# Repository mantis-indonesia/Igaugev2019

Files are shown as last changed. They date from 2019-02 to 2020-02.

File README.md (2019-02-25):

# Igaugev2019
Open source hardware water pressure sensor measurement system using Arduino Mega 2560

# Development
This system develop by Team MANTIS ID collaborate with USAID - IUWASH PLUS, PDAM Tirta Pakuan Kota Bogor, PDAM Tirta Patriot Kota Bekasi, and PDAM Tirta Asasta Kota Depok

# Folder
1. **Arduino Library** : All arduino external library used in this development
2. **Igauge_V2019** : Arduino Sketch used in this system
3. **Manual & Material** : All datasheet, and learning materials from components used in this system
4. **WEMOS_IGAUGE** : Arduino sketch for ESP Unit System
5. **nRFRangeTestRX** : Arduino sketch for NRF24L01 Experiment. This sketch used in server side
6. **nRFRangeTestTX** : Arduino sketch for NRF24L01 Experiment. This sketch used in transmitter side

# Developer
- Hollanda Arief Kusuma : github.com/hollandacocobear
- Rady P

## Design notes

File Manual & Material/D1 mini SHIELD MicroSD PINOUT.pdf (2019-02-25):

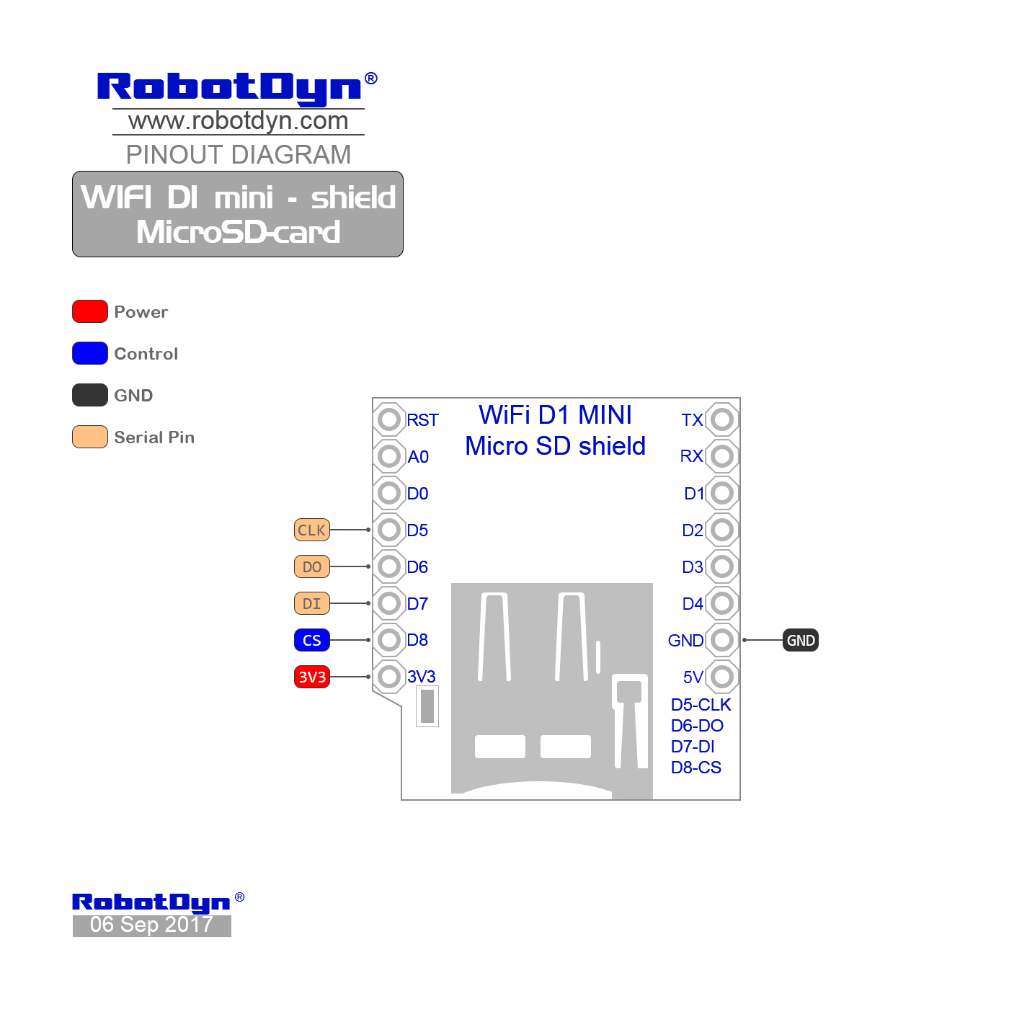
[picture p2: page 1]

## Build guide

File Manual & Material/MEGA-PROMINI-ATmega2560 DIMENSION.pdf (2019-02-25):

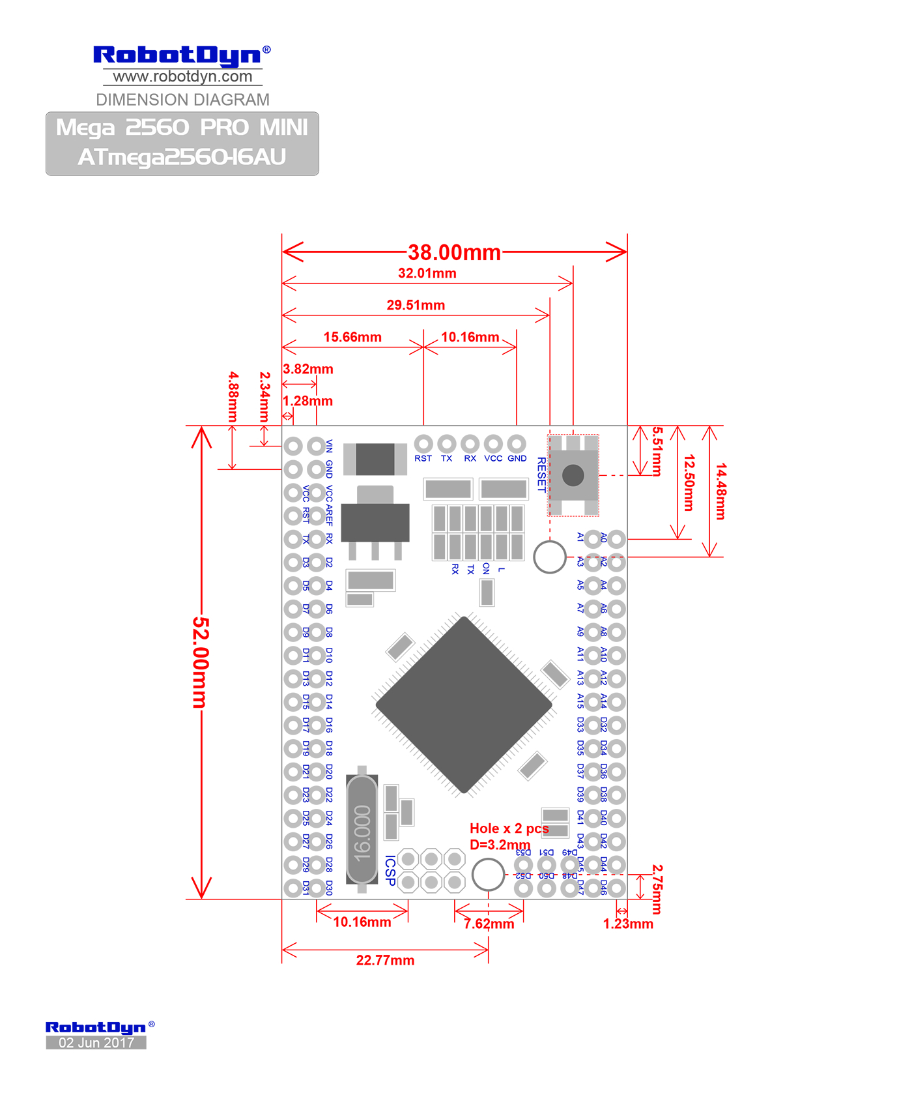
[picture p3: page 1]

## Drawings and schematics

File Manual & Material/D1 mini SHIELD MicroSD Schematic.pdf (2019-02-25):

11

22

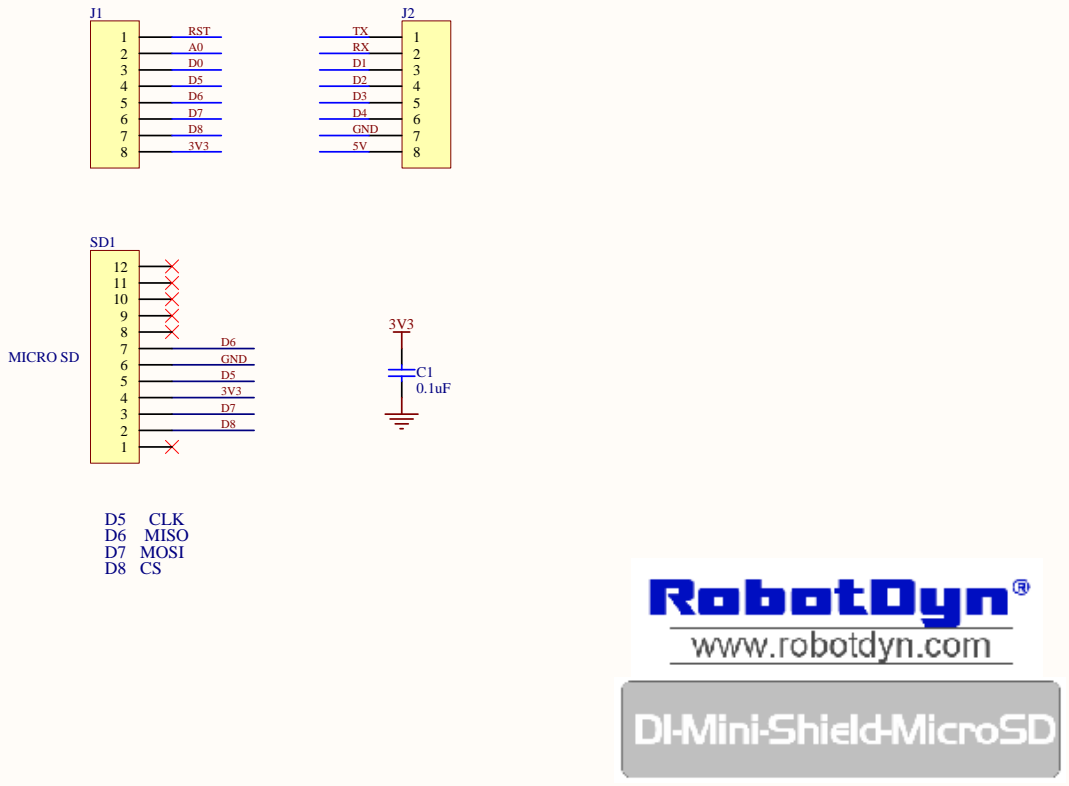
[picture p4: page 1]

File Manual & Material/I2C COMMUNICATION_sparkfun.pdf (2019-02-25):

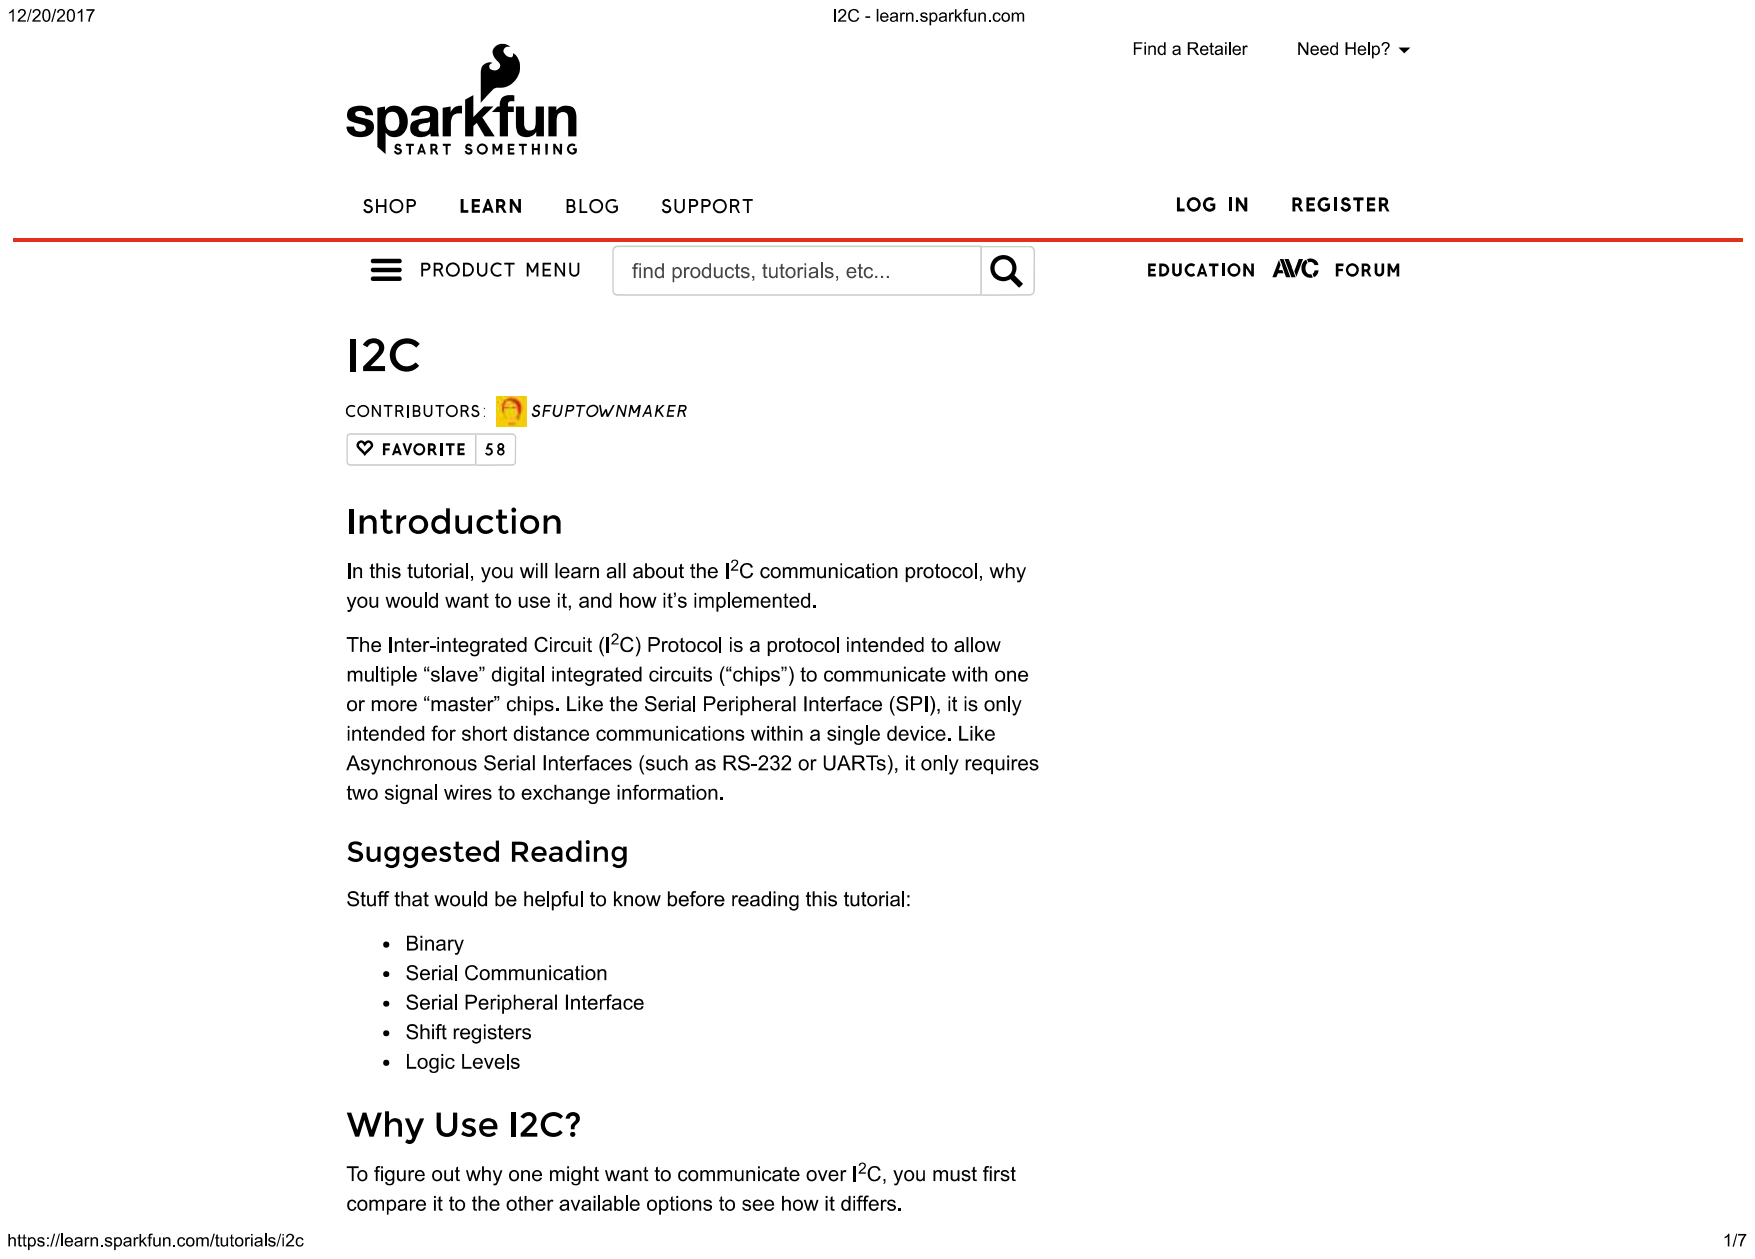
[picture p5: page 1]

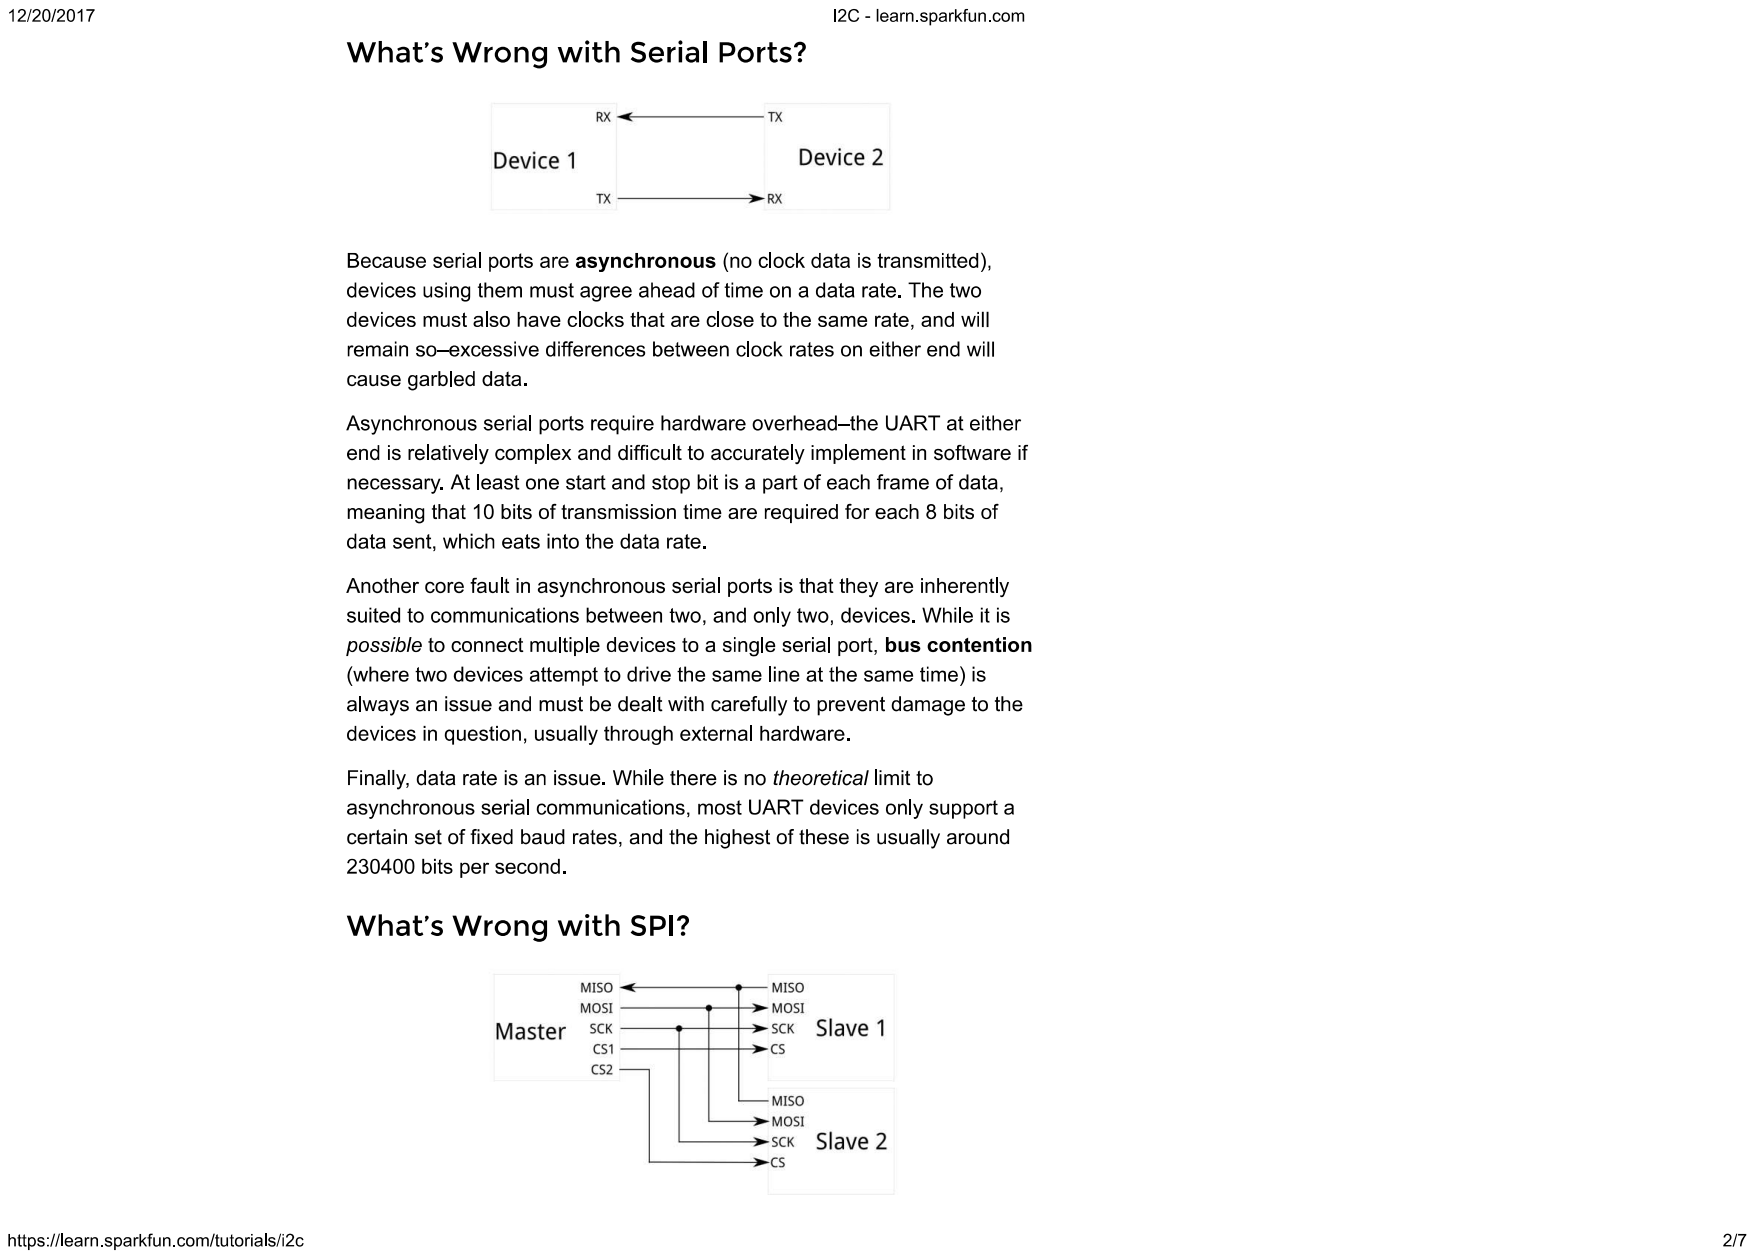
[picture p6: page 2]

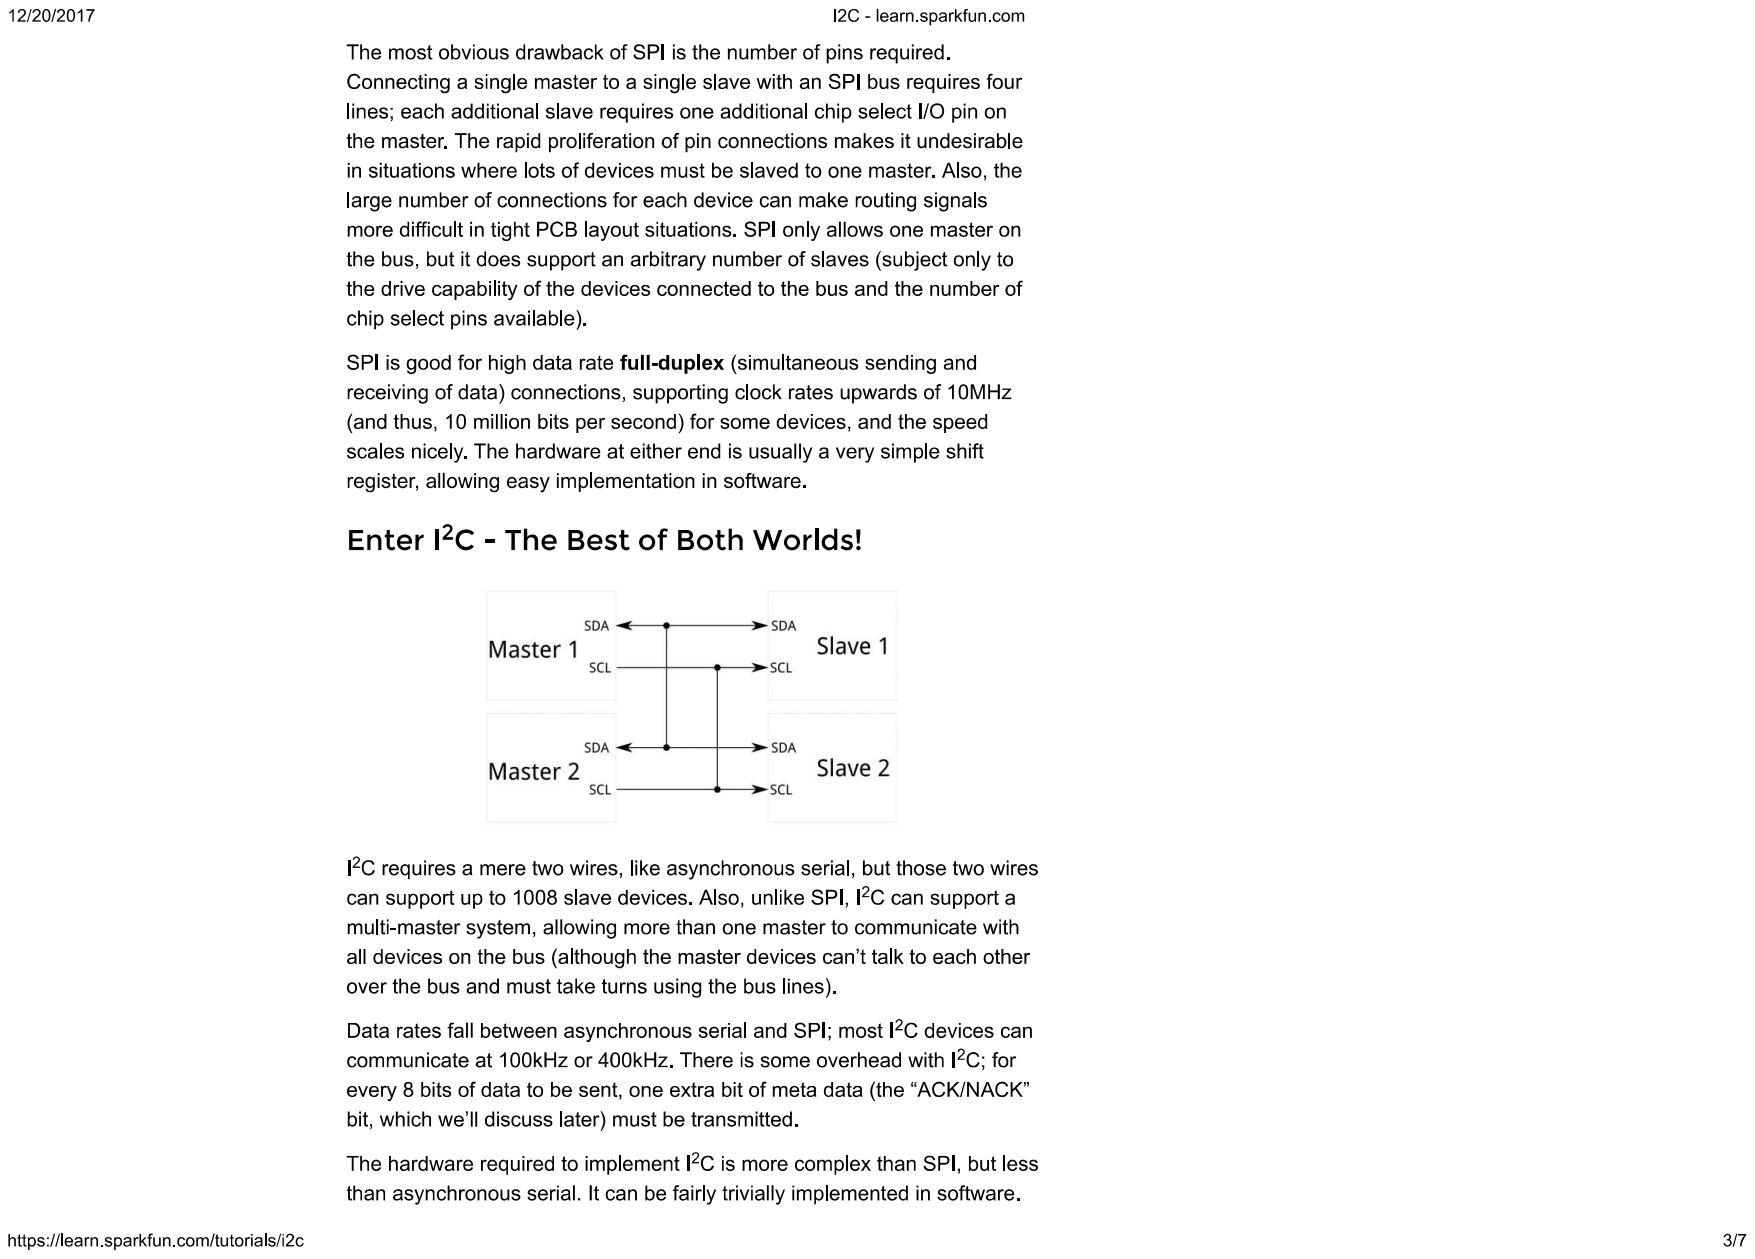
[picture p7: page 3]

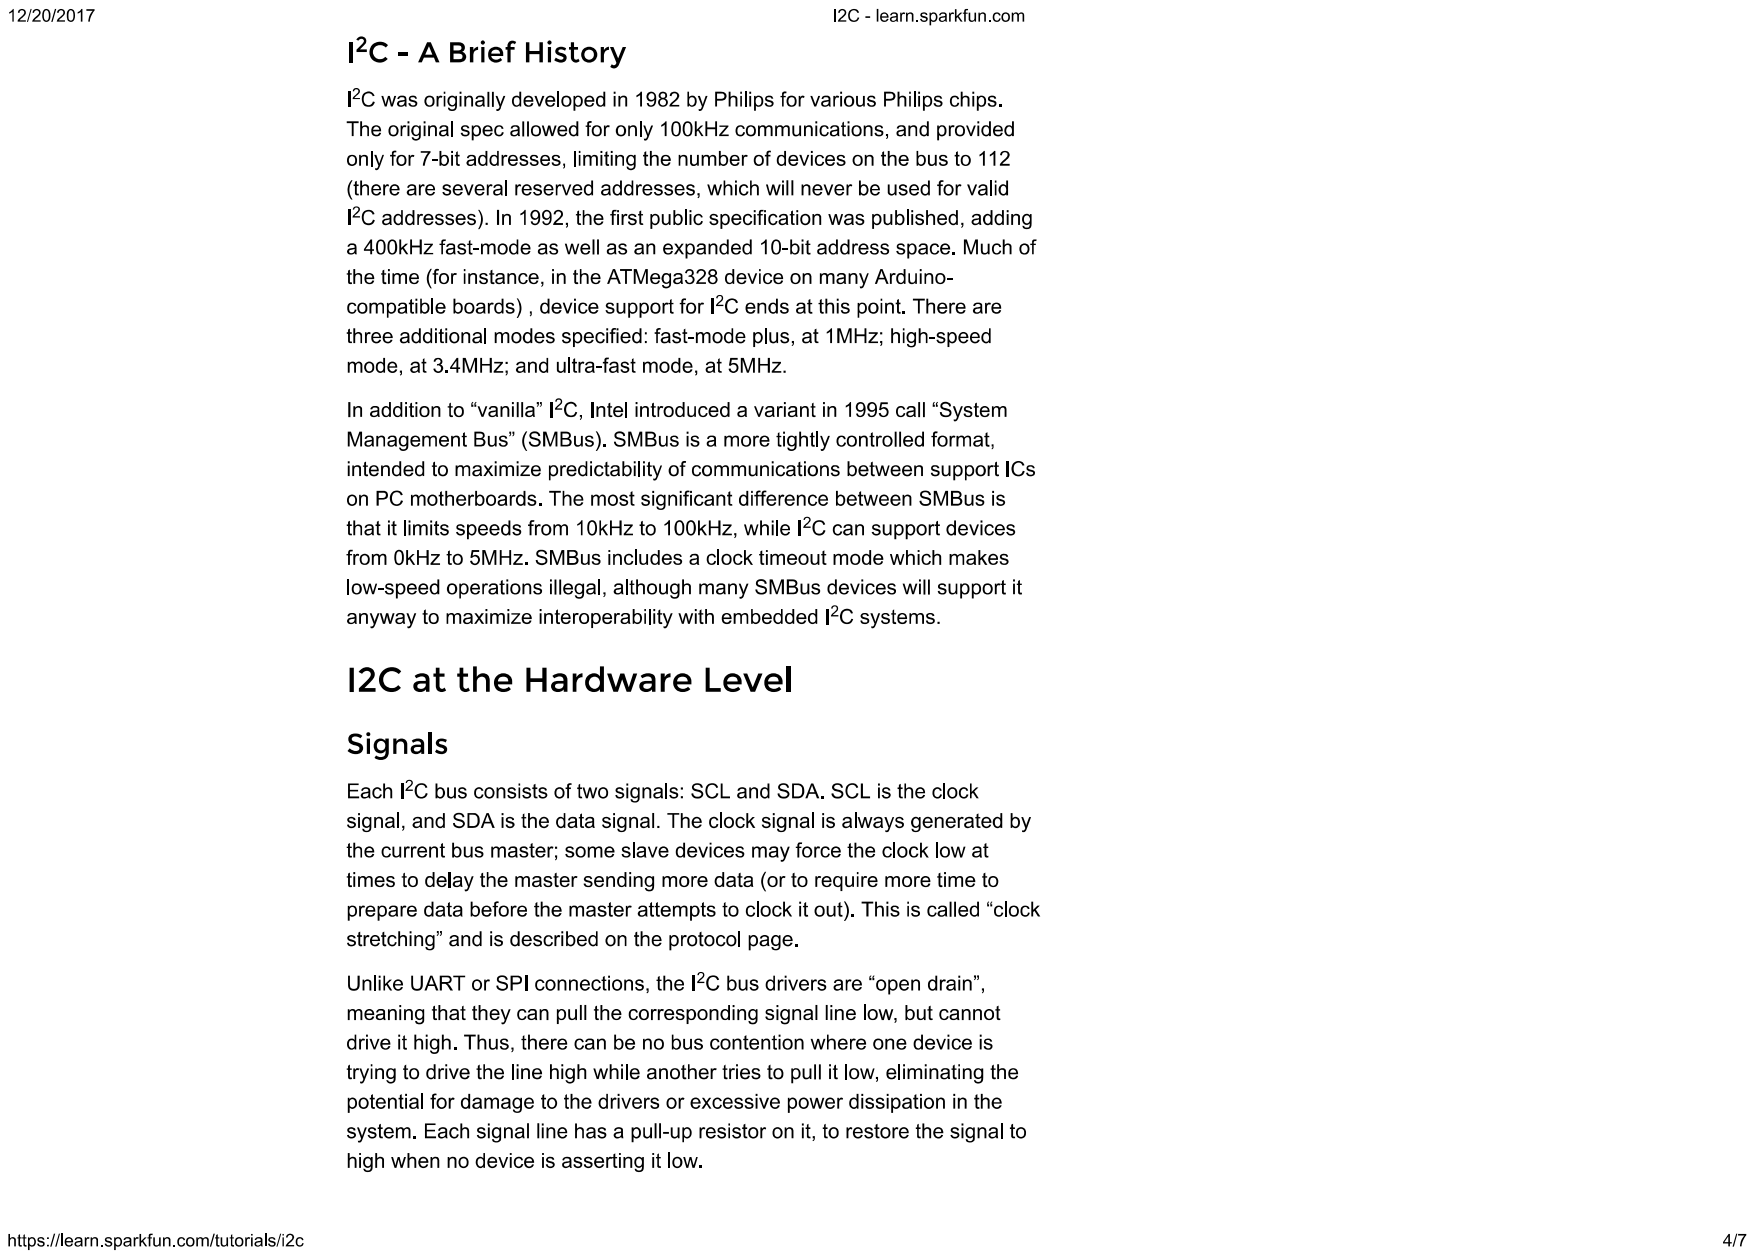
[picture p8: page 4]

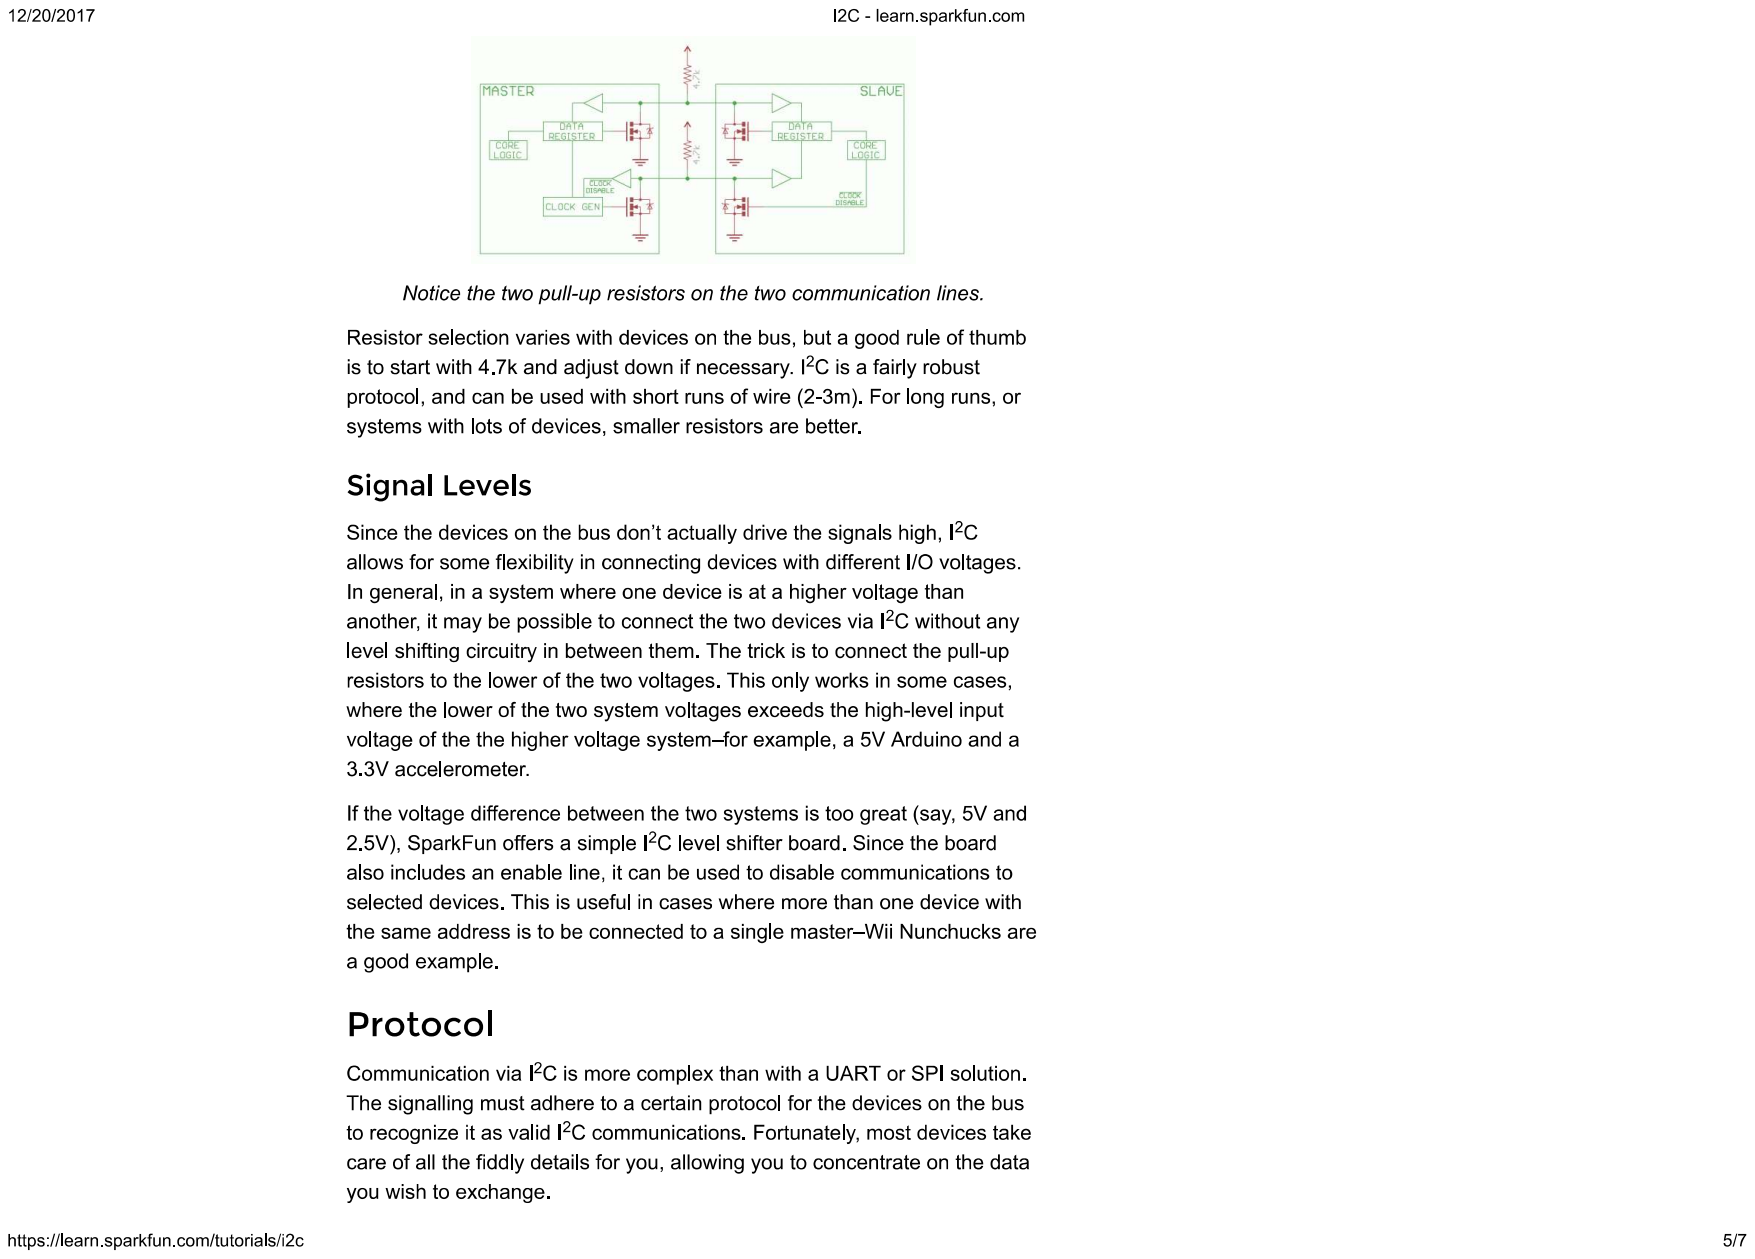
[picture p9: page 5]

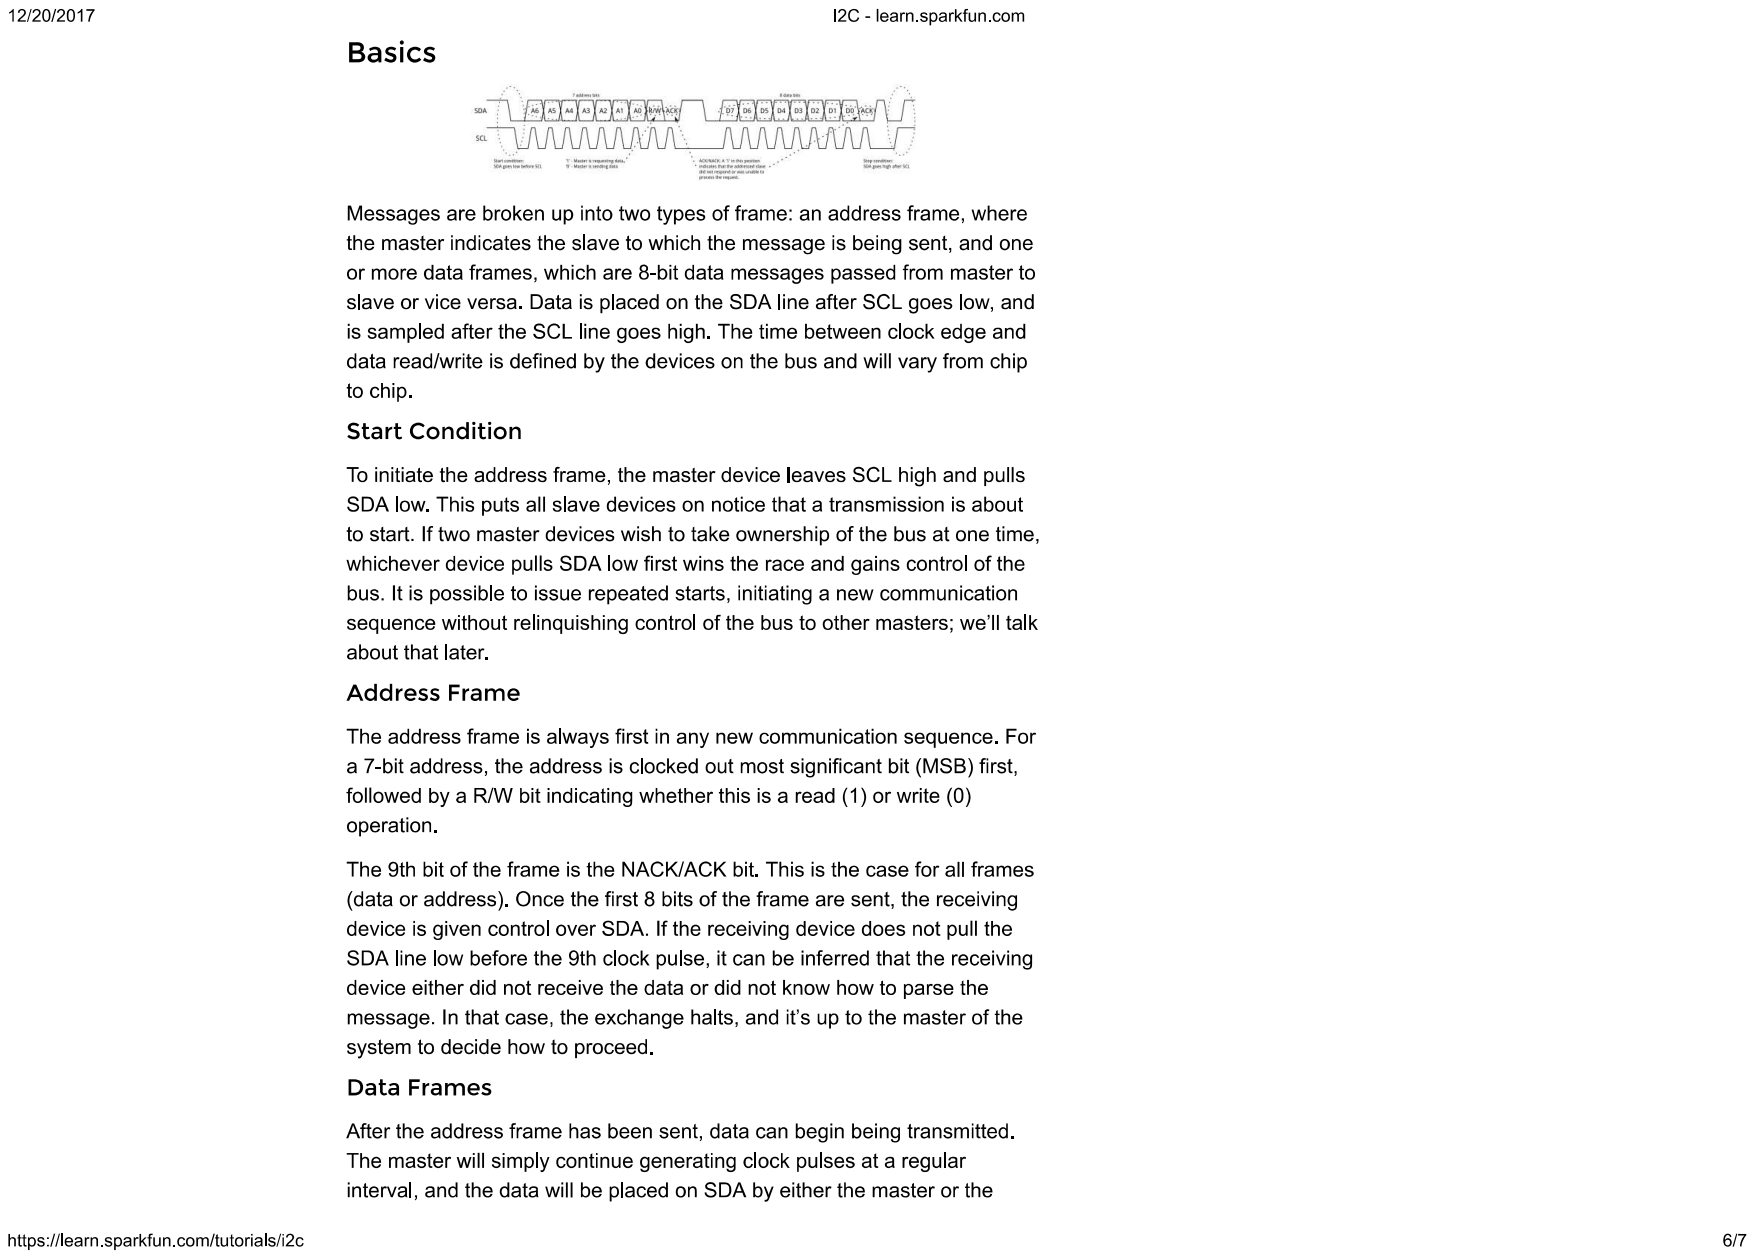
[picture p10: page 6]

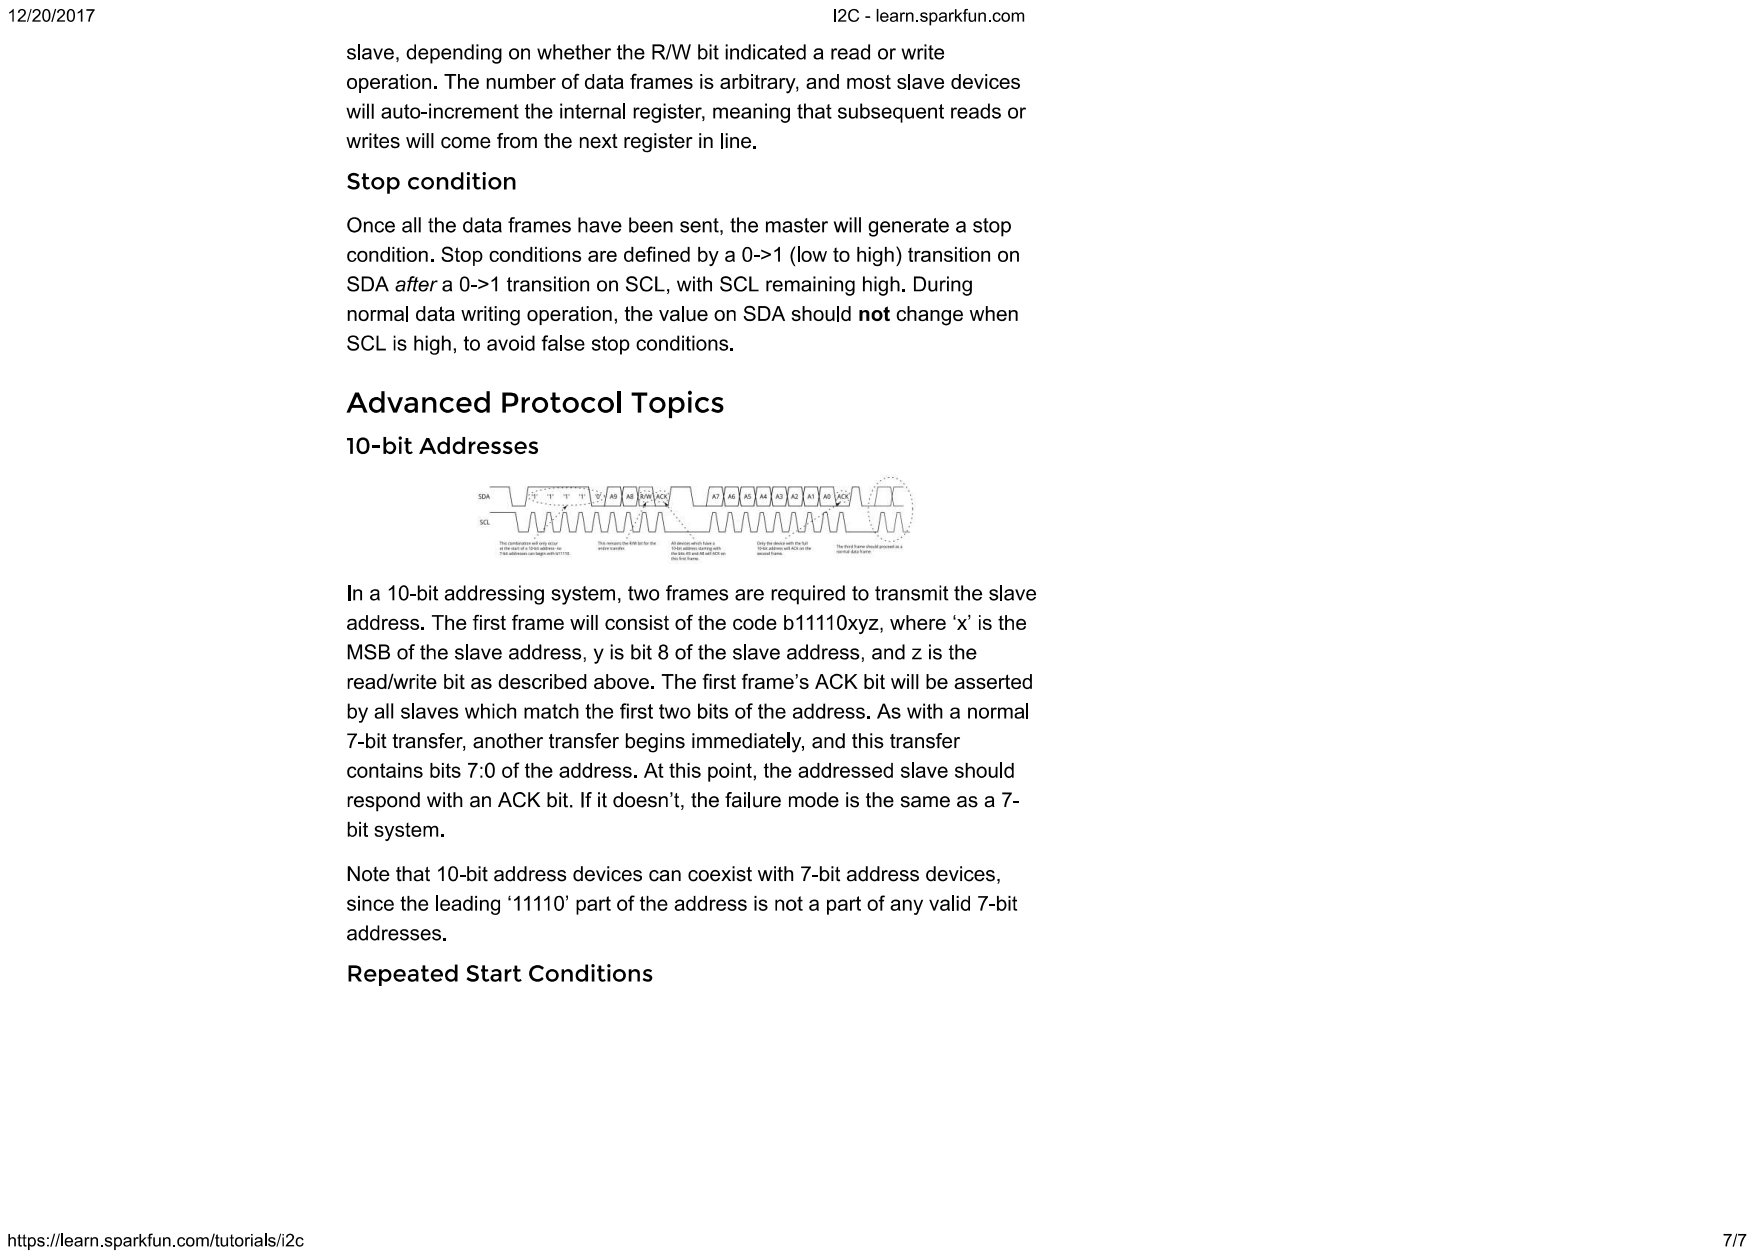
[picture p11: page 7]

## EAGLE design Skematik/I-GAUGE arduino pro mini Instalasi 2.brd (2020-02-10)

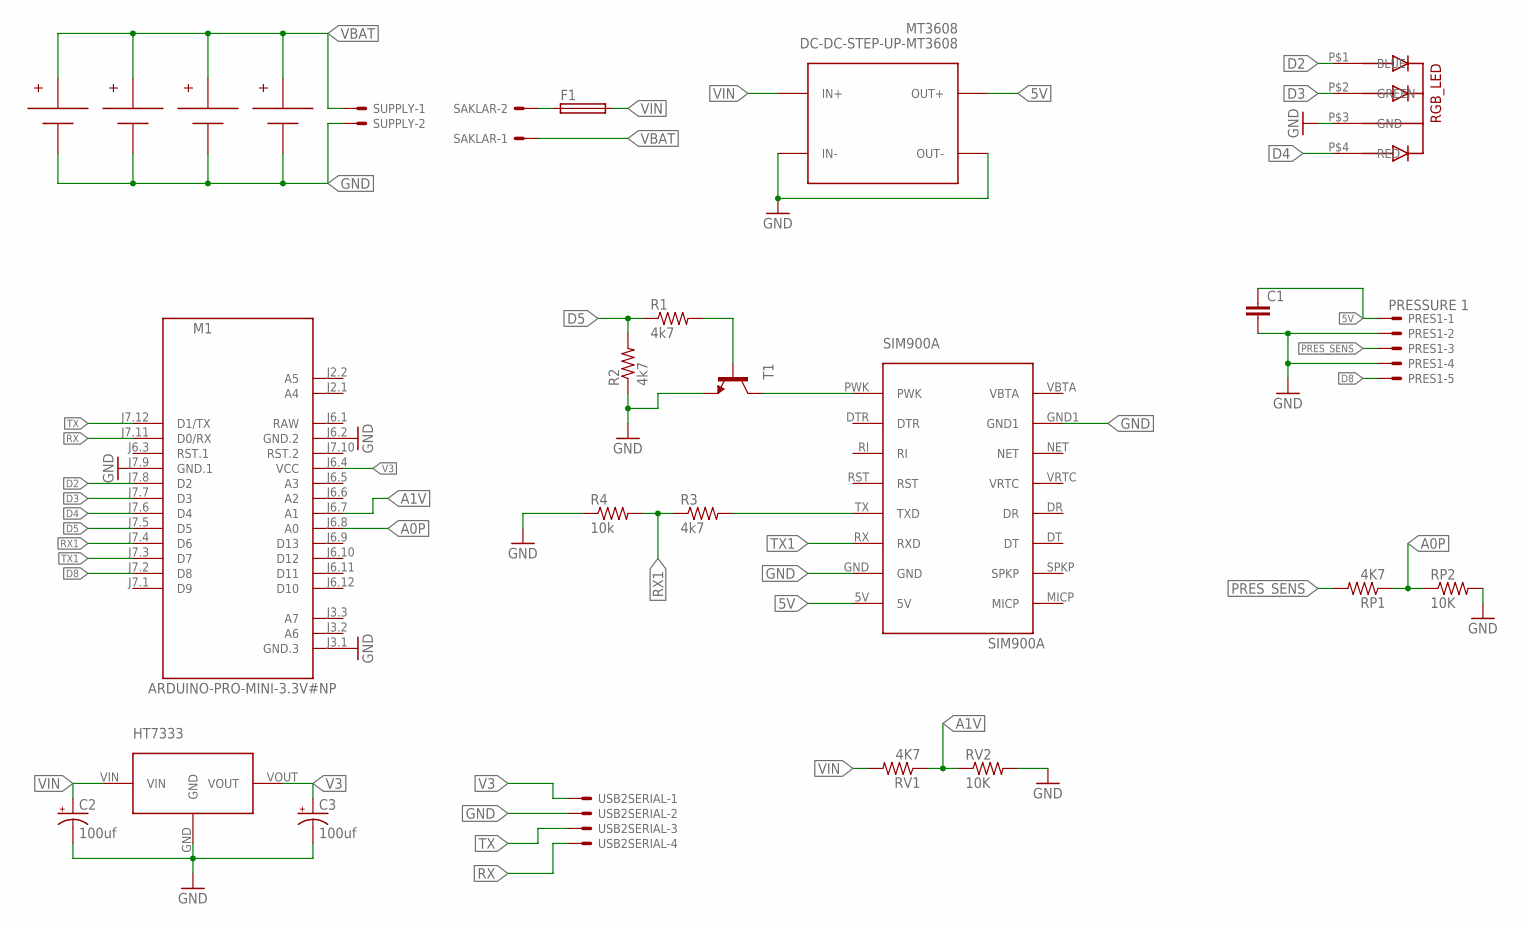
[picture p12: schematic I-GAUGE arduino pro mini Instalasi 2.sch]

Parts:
C1: C-EUC1206; C1206
C2, C3: 100uf; CT7343
F1: FUSESH22,5; SH22,5
HT7333: HT7333_SOT89; SOT89
M1: ARDUINO-PRO-MINI-3.3V#NP; ARDUINO-PRO-MINI#NP
MT3608: DC-DC-STEP-UP-MT3608
PRES1: PRESSURE 1; JST-XH-05-PACKAGE-ROUND-PAD
R1, R2: 4k7; R1206
R3: 4k7; 1206
R4: 10k; R1206
RGB_LED: 5MMRGBLED; LED5MMRGB
RP1: 4K7; M1206
RP2: 10K; M1206
RV1: 4K7; M1206
RV2: 10K; M1206
SAKLAR: JST-XH-02-PIN-ROUND-PAD; JST-XH-02-PACKAGE-ROUND-PAD
SUPPLY: JST-XH-02-PIN-ROUND-PAD; JST-XH-02-PACKAGE-ROUND-PAD
T1: -NPN-TO92; TO92
U$1, U$2, U$3, U$4: SMT18650; 18650SMT
U$6: SIM900A
USB2SERIAL: JST-XH-04-PIN-ROUND-PAD; JST-XH-04-PACKAGE-ROUND-PAD

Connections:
5V: C1.1, MT3608.OUT+, PRES1.1, U$6.5V
A0P: M1.J6.8 (A0), RP1.1, RP2.1
A1V: M1.J6.7 (A1), RV1.1, RV2.1
D2: M1.J7.8 (D2), RGB_LED.P$1 (BLUE)
D3: M1.J7.7 (D3), RGB_LED.P$2 (GREEN)
D4: M1.J7.6 (D4), RGB_LED.P$4 (RED)
D5: M1.J7.5 (D5), R1.1, R2.2
D8: M1.J7.2 (D8), PRES1.5
GND: C1.2, C2.-, C3.-, HT7333.GND, M1.J3.1 (GND.3), M1.J6.2 (GND.2), M1.J7.9 (GND.1), MT3608.IN-, MT3608.OUT-, PRES1.2, PRES1.4, R2.1, R4.1, RGB_LED.P$3 (GND), RP2.2, RV2.2, SUPPLY.2, T1.1 (E), U$1.BATTERY_NEGATIVE (-), U$2.BATTERY_NEGATIVE (-), U$3.BATTERY_NEGATIVE (-), U$4.BATTERY_NEGATIVE (-), U$6.GND, U$6.GND1, USB2SERIAL.2
unnamed: R1.2, T1.2 (B)
unnamed: R3.2, U$6.TX (TXD)
unnamed: T1.3 (C), U$6.PWK
PRES_SENS: PRES1.3, RP1.2
RAW: M1.J6.1 (RAW)
RX: M1.J7.11 (D0/RX), USB2SERIAL.4
RX1: M1.J7.4 (D6), R3.1, R4.2
TX: M1.J7.12 (D1/TX), USB2SERIAL.3
TX1: M1.J7.3 (D7), U$6.RX (RXD)
V3: C3.+, HT7333.VOUT, M1.J6.4 (VCC), USB2SERIAL.1
VBAT: SAKLAR.1, SUPPLY.1, U$1.BATTERY_POSITIVE (+), U$2.BATTERY_POSITIVE (+), U$3.BATTERY_POSITIVE (+), U$4.BATTERY_POSITIVE (+)
VCC: F1.1, SAKLAR.2
VIN: C2.+, F1.2, HT7333.VIN, MT3608.IN+, RV1.2

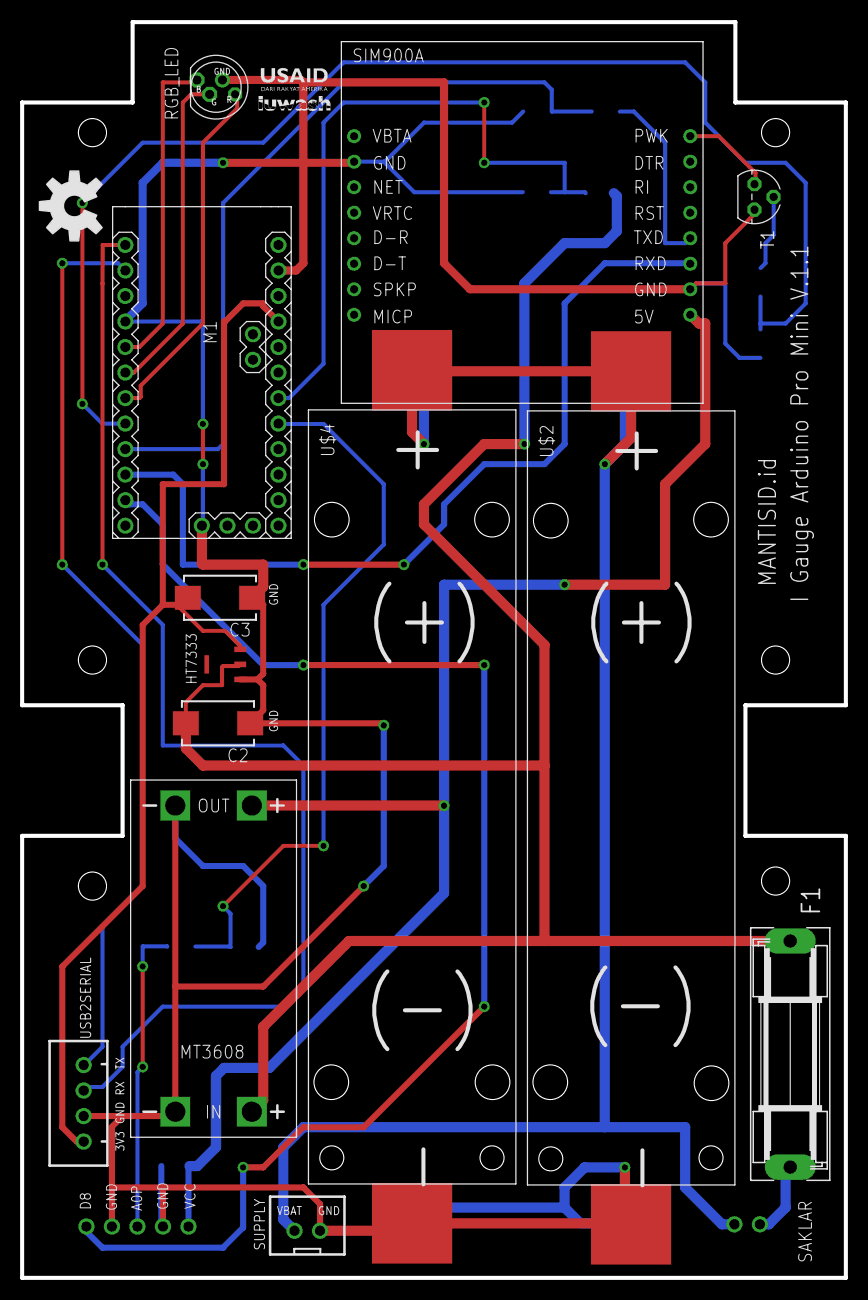
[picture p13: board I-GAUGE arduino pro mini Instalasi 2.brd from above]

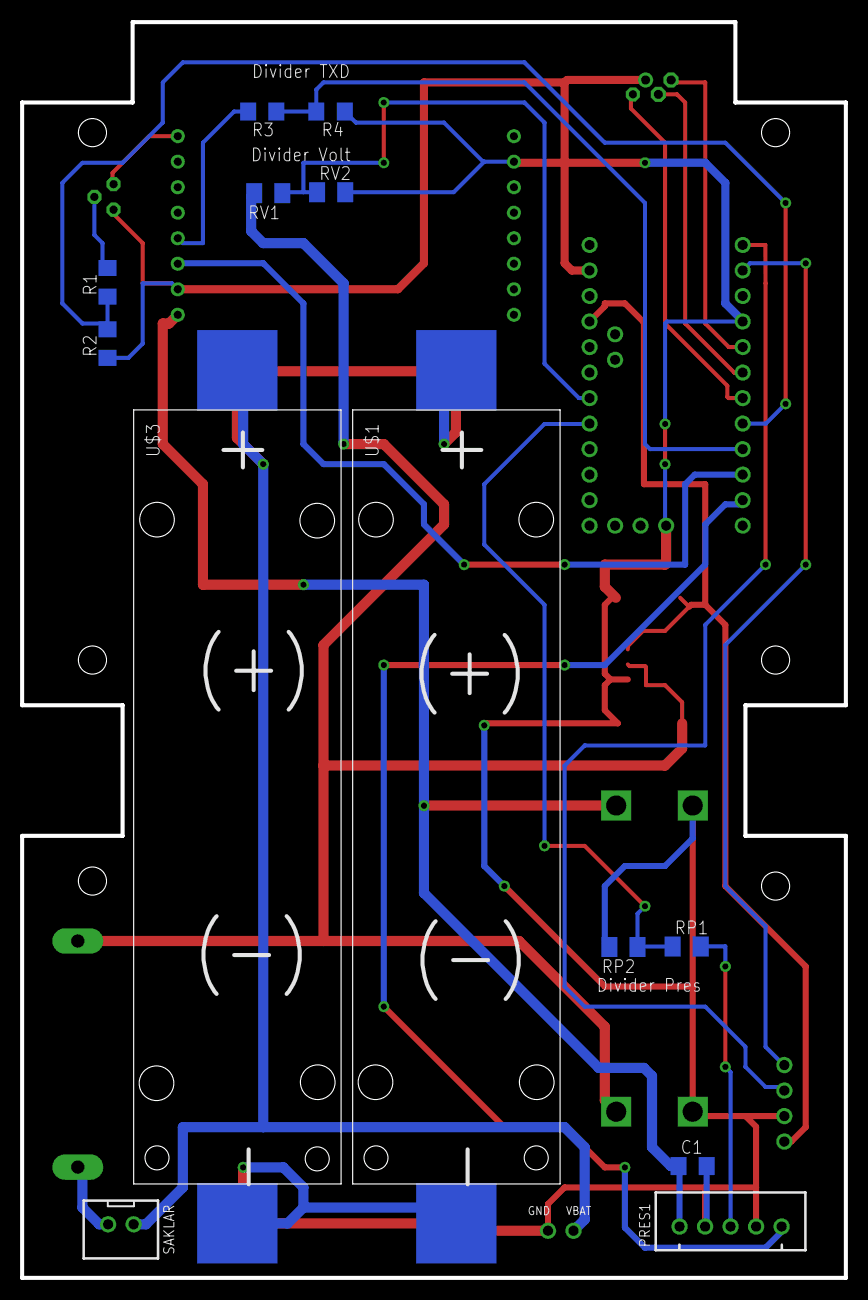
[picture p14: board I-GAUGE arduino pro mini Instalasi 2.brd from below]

Board: 2 copper layers, 82.0 x 125.0 mm, 27 parts (13 on the bottom side), 21 nets.

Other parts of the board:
U$7: OSHW-LOGO-L

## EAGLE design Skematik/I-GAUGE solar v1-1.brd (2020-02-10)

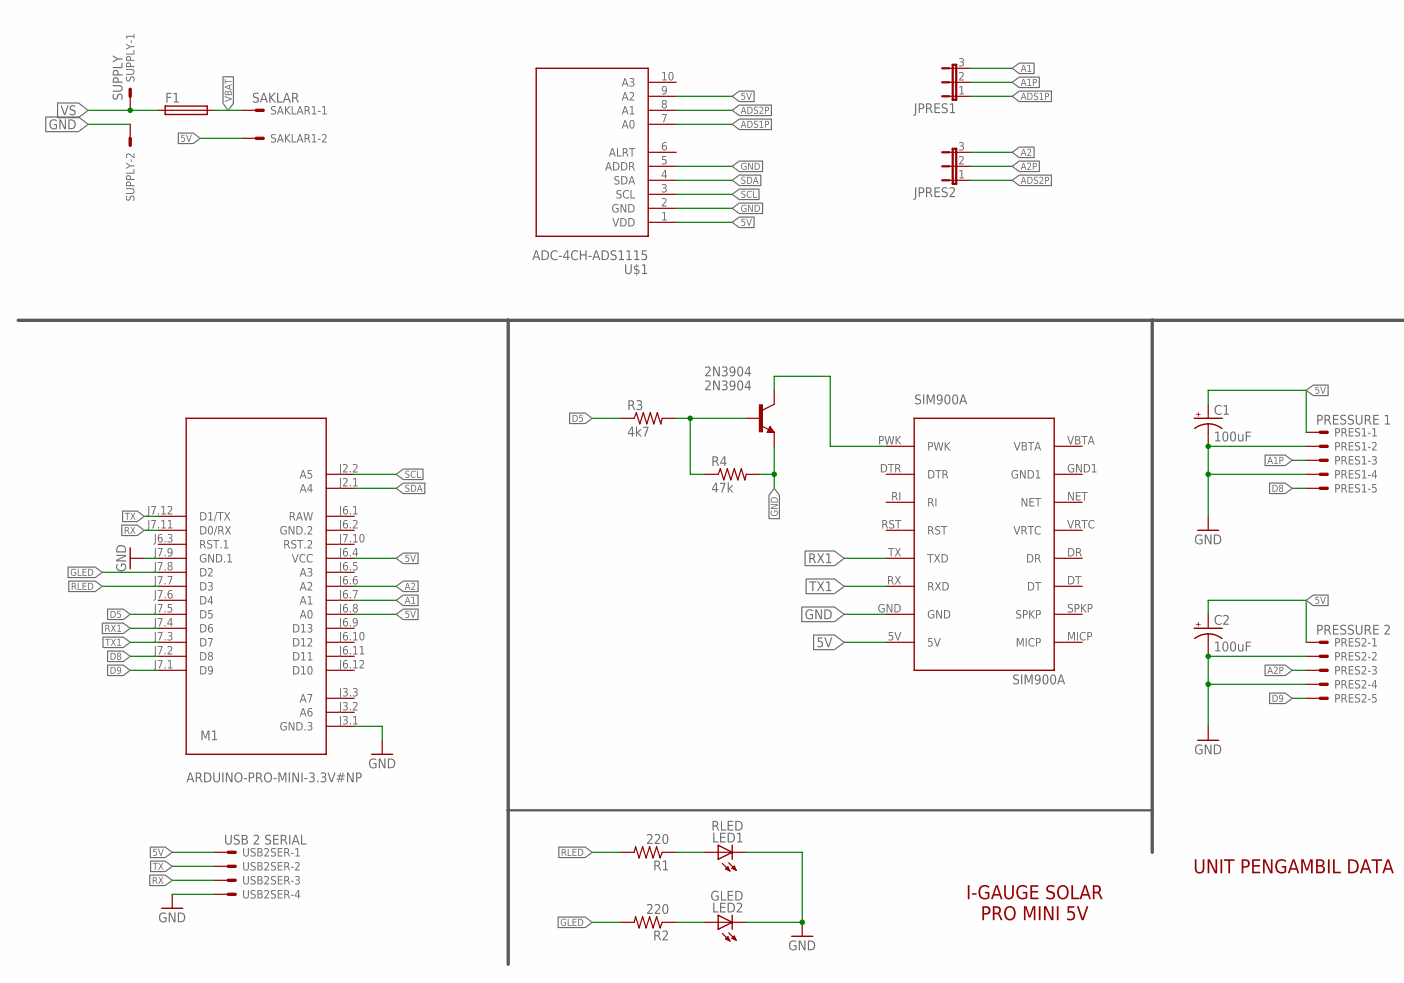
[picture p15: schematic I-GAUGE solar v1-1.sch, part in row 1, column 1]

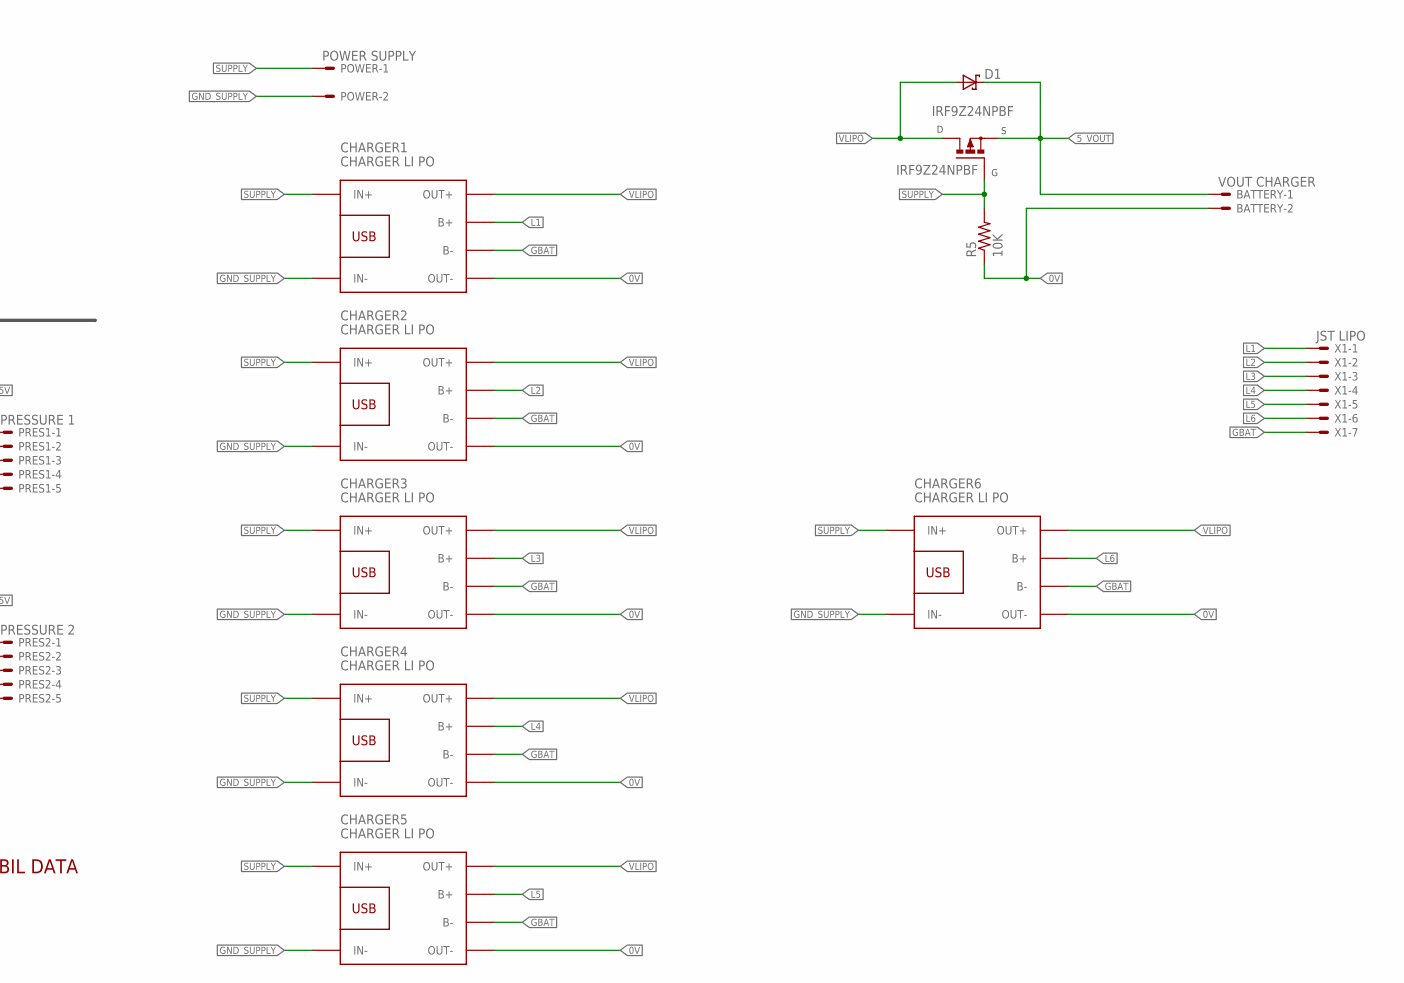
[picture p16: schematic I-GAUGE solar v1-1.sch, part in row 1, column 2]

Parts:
2N3904: 2N3904; TO92
BATTERY: VOUT CHARGER; JST-XH-02-PACKAGE-ROUND-PAD
C1, C2: 100uF; EIA7343
CHARGER1, CHARGER2, CHARGER3, CHARGER4, CHARGER5, CHARGER6: CHARGER LI PO; BATTERY-CHARGER-LI-PROT
D1: DS_E2L; E2LINE
F1: FUSESH22,5; SH22,5
IRF9Z24NPBF: IRF9Z24NPBF; TO220BH
JPRES1, JPRES2: JP2E; JP2
LED1: RLED; LED5MM
LED2: GLED; LED5MM
M1: ARDUINO-PRO-MINI-3.3V#NP; ARDUINO-PRO-MINI#NP
POWER: POWER SUPPLY; JST-XH-02-PACKAGE-ROUND-PAD
PRES1: PRESSURE 1; JST-XH-05-PACKAGE-ROUND-PAD
PRES2: PRESSURE 2; JST-XH-05-PACKAGE-ROUND-PAD
R1, R2: 220; M1206
R3: 4k7; R0805
R4: 47k; R0805
R5: 10K; R0805
SAKLAR1: SAKLAR; JST-XH-02-PACKAGE-ROUND-PAD
SUPPLY: SUPPLY; JST-XH-02-PACKAGE-ROUND-PAD
U$1: ADC-4CH-ADS1115
U$5: SIM900A
USB2SER: USB 2 SERIAL; JST-XH-04-PACKAGE-ROUND-PAD
X1: JST LIPO; JST-XH-07-PACKAGE-ROUND-PAD

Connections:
0V: BATTERY.2, CHARGER1.OUT-, CHARGER2.OUT-, CHARGER3.OUT-, CHARGER4.OUT-, CHARGER5.OUT-, CHARGER6.OUT-, R5.1
5V: C1.A (+), C2.A (+), M1.J6.4 (VCC), M1.J6.8 (A0), PRES1.1, PRES2.1, SAKLAR1.2, U$1.1 (VDD), U$1.9 (A2), U$5.5V, USB2SER.1
5_VOUT: BATTERY.1, D1.1 (K), IRF9Z24NPBF.S
A1: JPRES1.3, M1.J6.7 (A1)
A1P: JPRES1.2, PRES1.3
A2: JPRES2.3, M1.J6.6 (A2)
A2P: JPRES2.2, PRES2.3
ADS1P: JPRES1.1, U$1.7 (A0)
ADS2P: JPRES2.1, U$1.8 (A1)
D5: M1.J7.5 (D5), R3.1
D8: M1.J7.2 (D8), PRES1.5
D9: M1.J7.1 (D9), PRES2.5
GBAT: CHARGER1.B-, CHARGER2.B-, CHARGER3.B-, CHARGER4.B-, CHARGER5.B-, CHARGER6.B-, X1.7
GLED: M1.J7.8 (D2), R2.2
GND: 2N3904.3 (E), C1.C (-), C2.C (-), LED1.K (C), LED2.K (C), M1.J3.1 (GND.3), M1.J7.9 (GND.1), PRES1.2, PRES1.4, PRES2.2, PRES2.4, R4.2, SUPPLY.2, U$1.2 (GND), U$1.5 (ADDR), U$5.GND, USB2SER.4
GND.2: M1.J6.2 (GND.2)
GND_SUPPLY: CHARGER1.IN-, CHARGER2.IN-, CHARGER3.IN-, CHARGER4.IN-, CHARGER5.IN-, CHARGER6.IN-, POWER.2
L1: CHARGER1.B+, X1.1
L2: CHARGER2.B+, X1.2
L3: CHARGER3.B+, X1.3
L4: CHARGER4.B+, X1.4
L5: CHARGER5.B+, X1.5
L6: CHARGER6.B+, X1.6
unnamed: 2N3904.1 (C), U$5.PWK
unnamed: LED1.A, R1.1
unnamed: LED2.A, R2.1
unnamed: 2N3904.2 (B), R3.2, R4.1
RAW: M1.J6.1 (RAW)
RLED: M1.J7.7 (D3), R1.2
RX: M1.J7.11 (D0/RX), USB2SER.3
RX1: M1.J7.4 (D6), U$5.TX (TXD)
SCL: M1.J2.2 (A5), U$1.3 (SCL)
SDA: M1.J2.1 (A4), U$1.4 (SDA)
SUPPLY: CHARGER1.IN+, CHARGER2.IN+, CHARGER3.IN+, CHARGER4.IN+, CHARGER5.IN+, CHARGER6.IN+, IRF9Z24NPBF.G, POWER.1, R5.2
TX: M1.J7.12 (D1/TX), USB2SER.2
TX1: M1.J7.3 (D7), U$5.RX (RXD)
VBAT: F1.2, SAKLAR1.1
VLIPO: CHARGER1.OUT+, CHARGER2.OUT+, CHARGER3.OUT+, CHARGER4.OUT+, CHARGER5.OUT+, CHARGER6.OUT+, D1.2 (A), IRF9Z24NPBF.D
VS: F1.1, SUPPLY.1

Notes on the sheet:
I-GAUGE SOLAR PRO MINI 5V
UNIT PENGAMBIL DATA

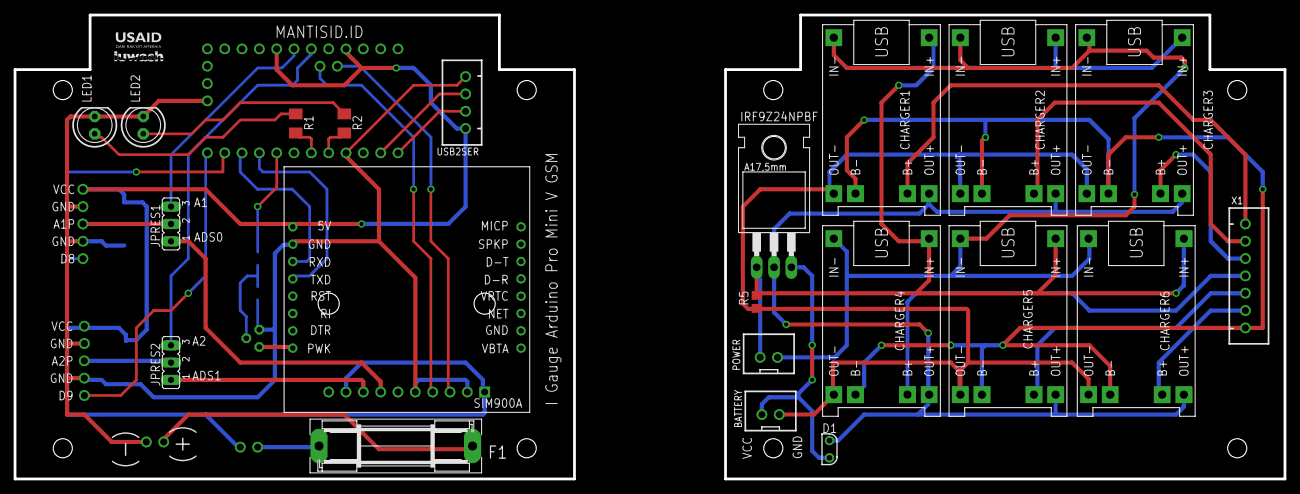
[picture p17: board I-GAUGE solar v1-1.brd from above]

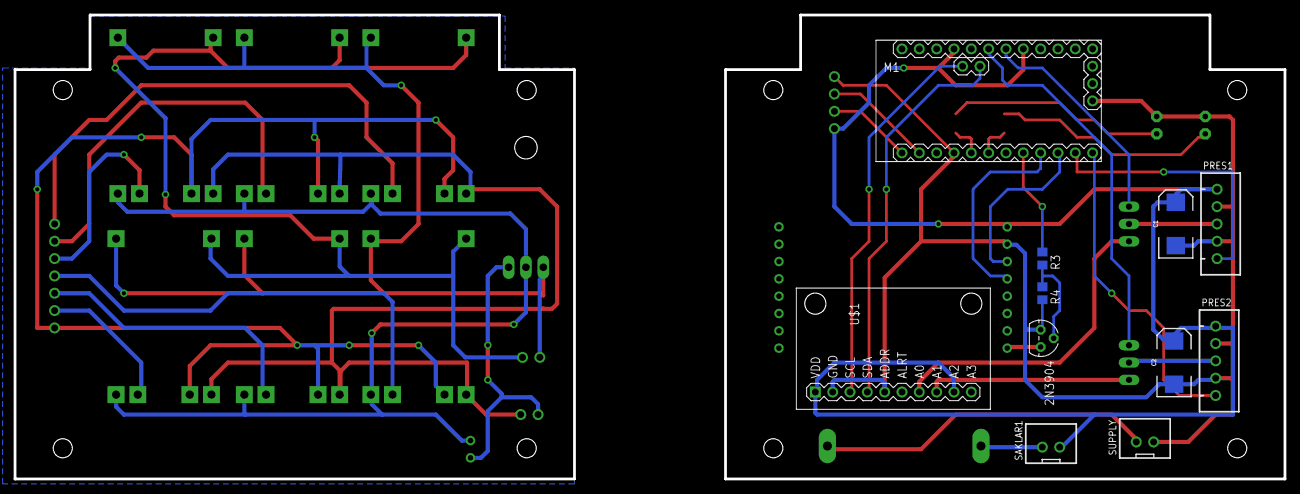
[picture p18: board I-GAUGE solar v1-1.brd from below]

Board: 2 copper layers, 186.1 x 68.0 mm, 32 parts (11 on the bottom side), 37 nets.

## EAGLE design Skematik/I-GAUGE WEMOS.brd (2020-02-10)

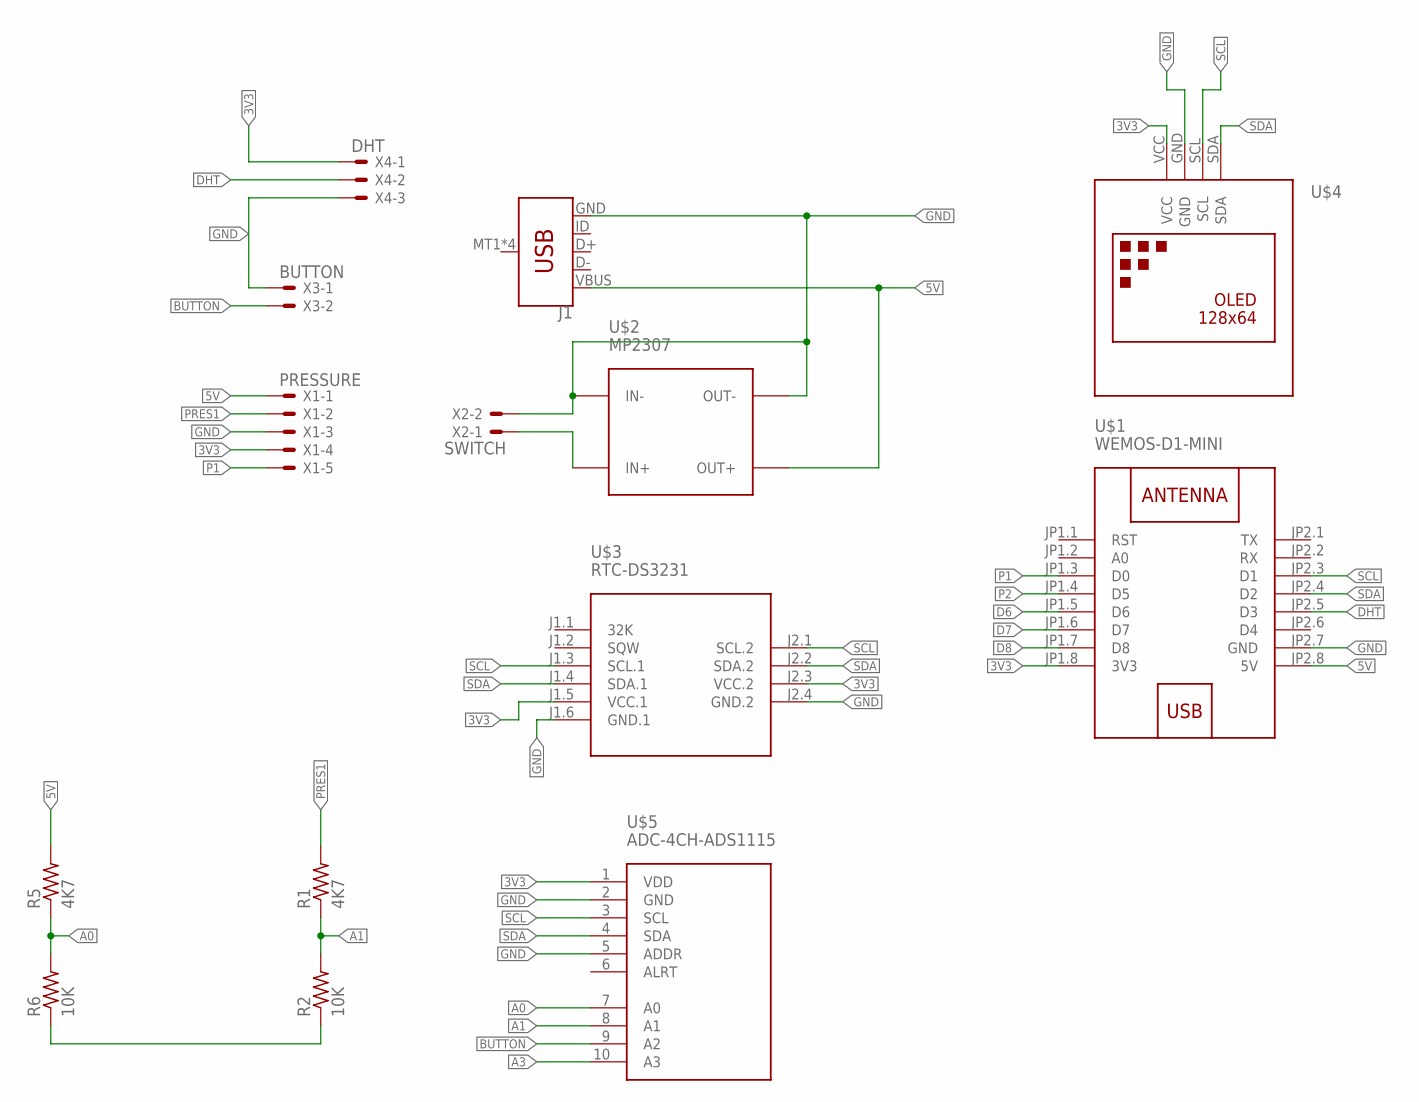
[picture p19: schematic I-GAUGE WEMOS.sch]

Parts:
J1: USB_MICRO-B_SMT; USB-MICROB
R1, R5: 4K7; R1210
R2, R6: 10K; R1210
U$1: WEMOS-D1-MINI
U$2: MP2307; DC-DC-STEP-DOWN-MP2307
U$3: RTC-DS3231; RTC-DS3231-AT24C32
U$4: DISPLAY-OLED-128X64-I2C
U$5: ADC-4CH-ADS1115
X1: PRESSURE; JST-XH-05-PACKAGE-LONG-PAD
X2: SWITCH; JST-XH-02-PACKAGE-LONG-PAD
X3: BUTTON; JST-XH-02-PACKAGE-LONG-PAD
X4: DHT; JST-XH-03-PACKAGE-LONG-PAD

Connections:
3V3: U$1.JP1.8 (3V3), U$3.J1.5 (VCC.1), U$3.J2.3 (VCC.2), U$4.VCC, U$5.1 (VDD), X1.4, X4.1
5V: J1.VBUS, R5.2, U$1.JP2.8 (5V), U$2.OUT+, X1.1
A0: R5.1, R6.2, U$5.7 (A0)
A1: R1.1, R2.2, U$5.8 (A1)
A3: U$5.10 (A3)
BUTTON: U$5.9 (A2), X3.2
D6: U$1.JP1.5 (D6)
D7: U$1.JP1.6 (D7)
D8: U$1.JP1.7 (D8)
DHT: U$1.JP2.5 (D3), X4.2
GND: J1.GND, R2.1, R6.1, U$1.JP2.7 (GND), U$2.IN-, U$2.OUT-, U$3.J1.6 (GND.1), U$3.J2.4 (GND.2), U$4.GND, U$5.2 (GND), U$5.5 (ADDR), X1.3, X2.2, X3.1, X4.3
unnamed: U$2.IN+, X2.1
P1: U$1.JP1.3 (D0), X1.5
P2: U$1.JP1.4 (D5)
PRES1: R1.2, X1.2
SCL: U$1.JP2.3 (D1), U$3.J1.3 (SCL.1), U$3.J2.1 (SCL.2), U$4.SCL, U$5.3 (SCL)
SDA: U$1.JP2.4 (D2), U$3.J1.4 (SDA.1), U$3.J2.2 (SDA.2), U$4.SDA, U$5.4 (SDA)

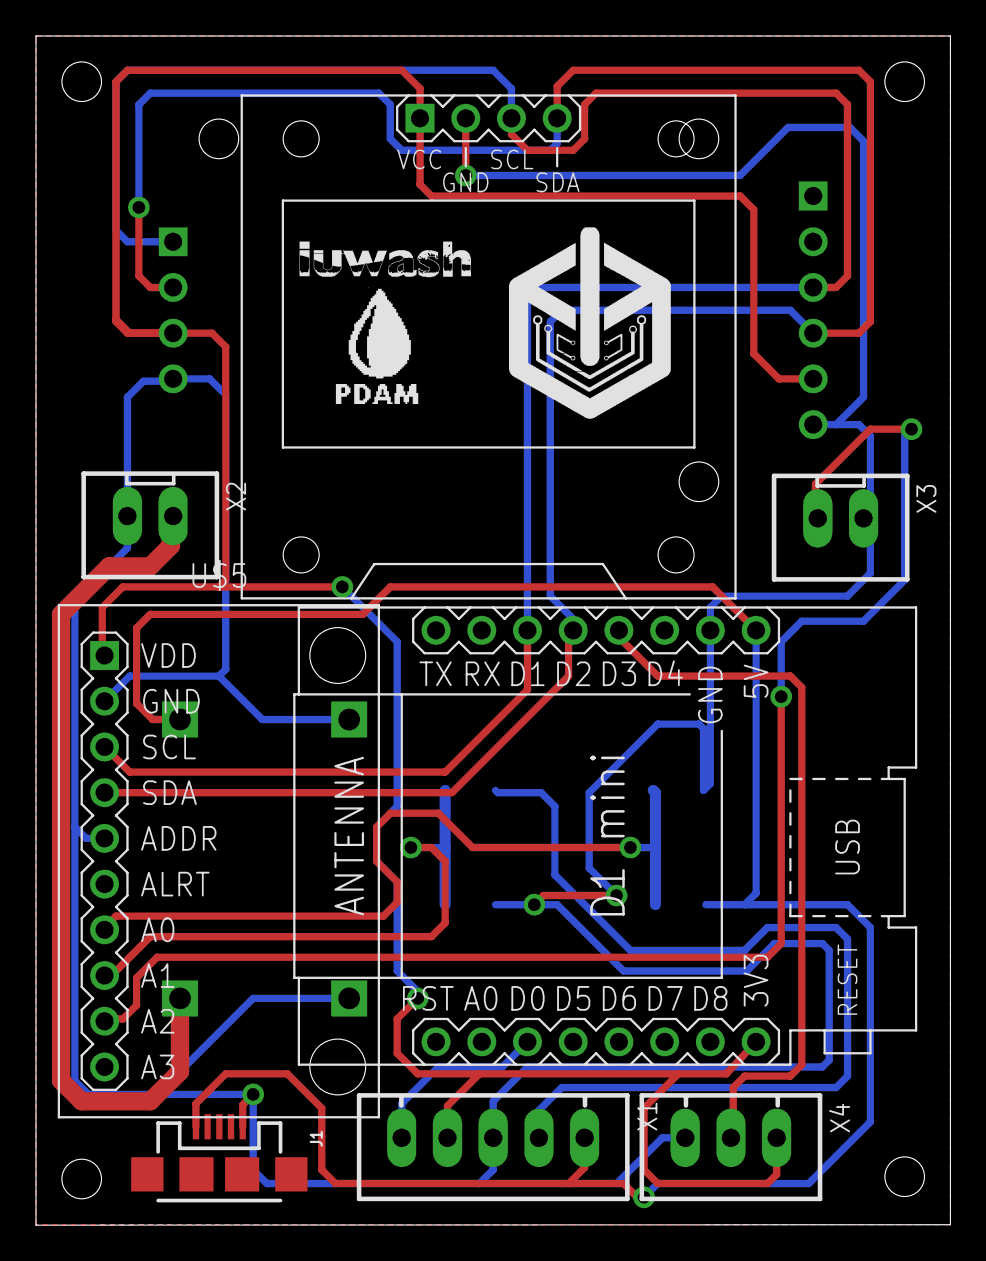
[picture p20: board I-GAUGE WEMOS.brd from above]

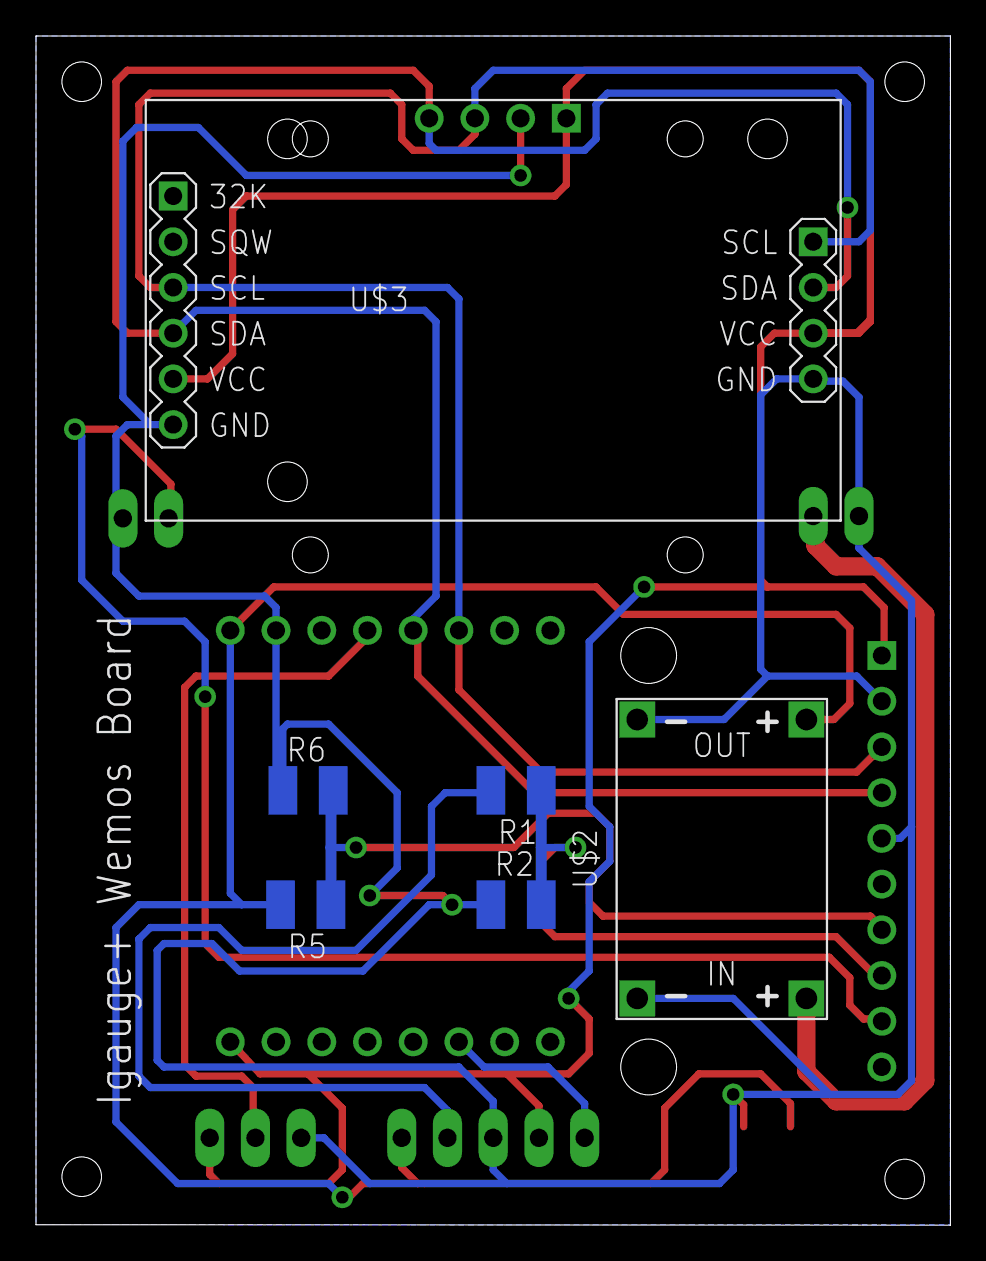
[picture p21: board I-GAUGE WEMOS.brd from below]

Board: 2 copper layers, 50.8 x 66.1 mm, 14 parts (6 on the bottom side), 12 nets.

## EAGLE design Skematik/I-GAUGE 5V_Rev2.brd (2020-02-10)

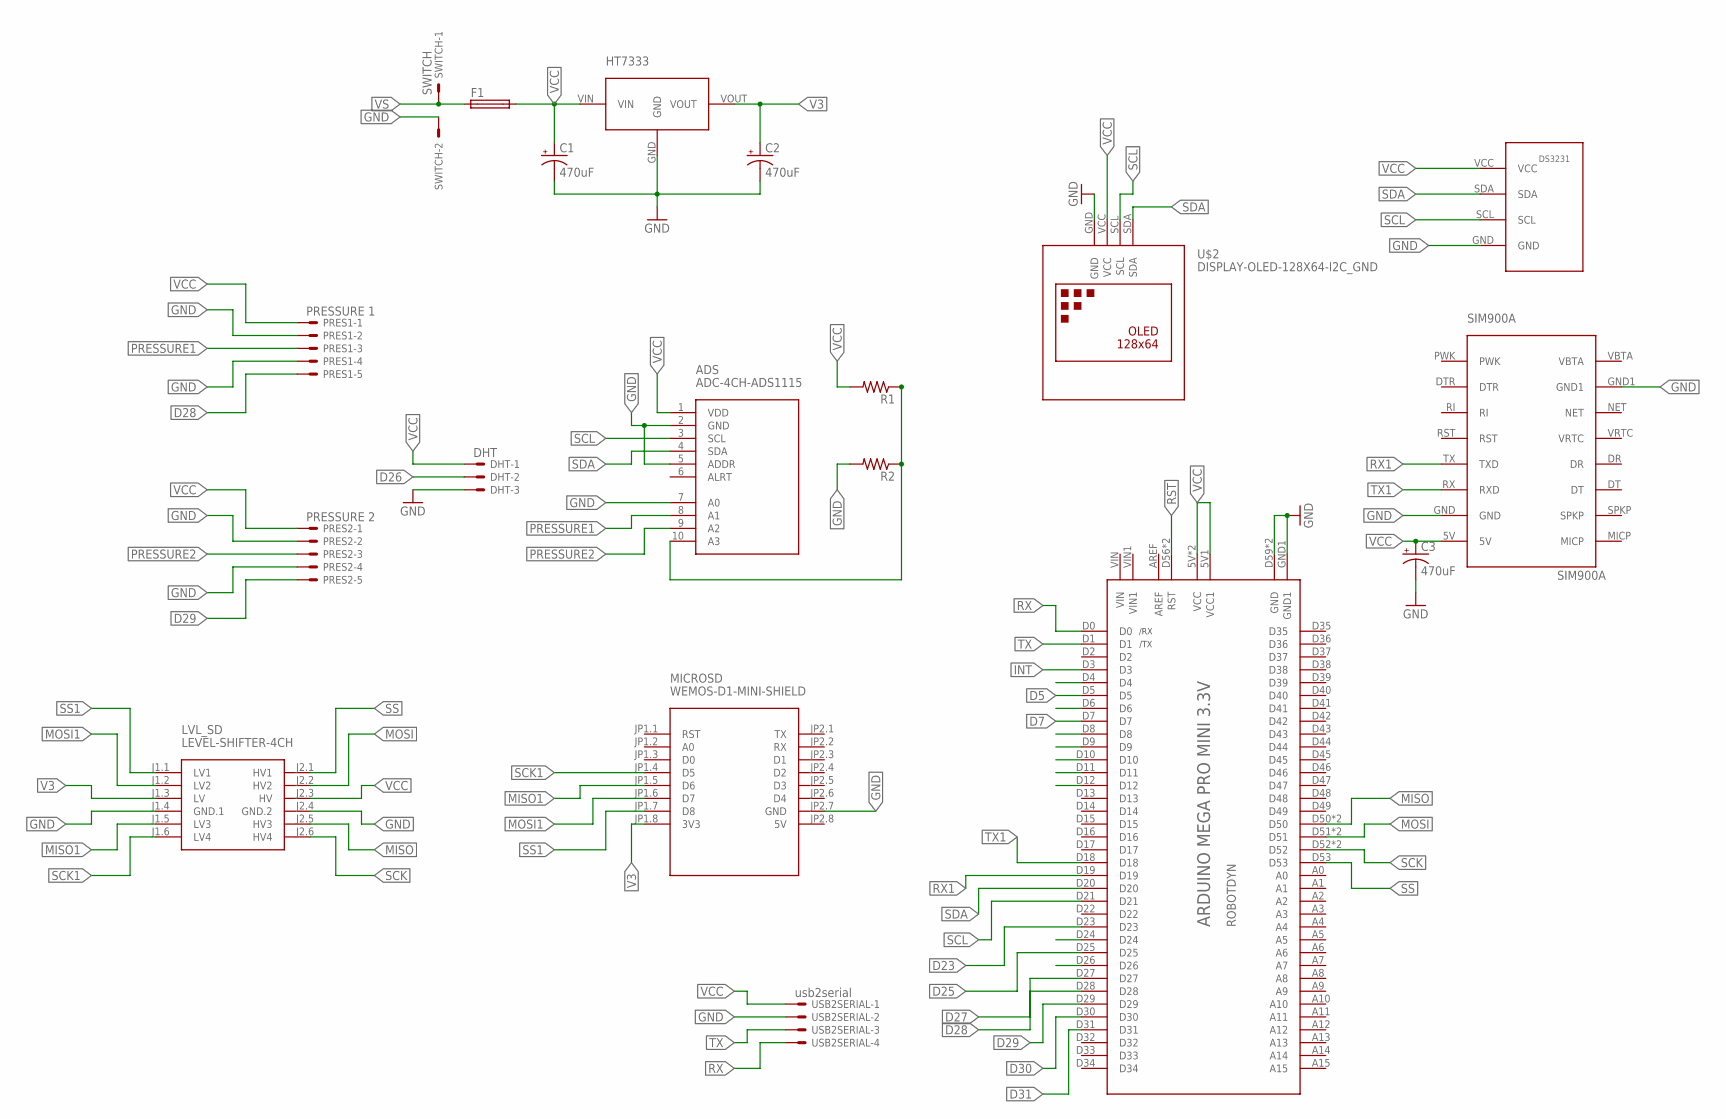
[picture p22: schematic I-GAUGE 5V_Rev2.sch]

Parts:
ADS: ADC-4CH-ADS1115
C1, C2, C3: 470uF; PANASONIC_G
DHT: DHT; JST-XH-03-PACKAGE-ROUND-PAD
F1: FUSESH22,5; SH22,5
HT7333: HT7333; SOT89
LVL_SD: LEVEL-SHIFTER-4CH
MICROSD: WEMOS-D1-MINI-SHIELD
PRES1: PRESSURE 1; JST-XH-05-PACKAGE-ROUND-PAD
PRES2: PRESSURE 2; JST-XH-05-PACKAGE-ROUND-PAD
R1, R2: R-US_M1206; M1206
SWITCH: SWITCH; JST-XH-02-PACKAGE-ROUND-PAD
U$1: MEGA-PRO-MINI
U$2: DISPLAY-OLED-128X64-I2C_GND
U$5: DS3231_RASP
U$6: SIM900A
USB2SERIAL: usb2serial; JST-XH-04-PACKAGE-ROUND-PAD

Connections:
5V: MICROSD.JP2.8 (5V)
D4: U$1.D4
D5: U$1.D5
D6: U$1.D6
D7: U$1.D7
D8: U$1.D8
D9: U$1.D9
D10: U$1.D10
D11: U$1.D11
D12: U$1.D12
D23: U$1.D23
D24: U$1.D24
D25: U$1.D25
D26: DHT.2, U$1.D26
D27: U$1.D27
D28: PRES1.5, U$1.D28
D29: PRES2.5, U$1.D29
D30: U$1.D30
D31: U$1.D31
GND: ADS.2 (GND), ADS.5 (ADDR), ADS.7 (A0), C1.-, C2.-, C3.-, DHT.3, HT7333.GND, LVL_SD.J1.4 (GND.1), LVL_SD.J2.4 (GND.2), MICROSD.JP2.7 (GND), PRES1.2, PRES1.4, PRES2.2, PRES2.4, R2.2, SWITCH.2, U$1.D59 (GND), U$1.GND, U$1.GND1, U$2.GND, U$5.GND, U$6.GND, U$6.GND1, USB2SERIAL.2
INT: U$1.D3
MISO: LVL_SD.J2.5 (HV3), U$1.D50, U$1.D54 (D50)
MISO1: LVL_SD.J1.5 (LV3), MICROSD.JP1.5 (D6)
MOSI: LVL_SD.J2.2 (HV2), U$1.D51, U$1.D58 (D51)
MOSI1: LVL_SD.J1.2 (LV2), MICROSD.JP1.6 (D7)
PRESSURE1: ADS.8 (A1), PRES1.3
PRESSURE2: ADS.9 (A2), PRES2.3
RST: U$1.D56 (RST), U$1.RST
RX: U$1.D0, USB2SERIAL.4
RX1: U$1.D19, U$6.TX (TXD)
SCK: LVL_SD.J2.6 (HV4), U$1.D52, U$1.D55 (D52)
SCK1: LVL_SD.J1.6 (LV4), MICROSD.JP1.4 (D5)
SCL: ADS.3 (SCL), U$1.D21, U$2.SCL, U$5.SCL
SDA: ADS.4 (SDA), U$1.D20, U$2.SDA, U$5.SDA
SS: LVL_SD.J2.1 (HV1), U$1.D53
SS1: LVL_SD.J1.1 (LV1), MICROSD.JP1.7 (D8)
TX: U$1.D1, USB2SERIAL.3
TX1: U$1.D18, U$6.RX (RXD)
V3: C2.+, HT7333.VOUT, LVL_SD.J1.3 (LV), MICROSD.JP1.8 (3V3)
VCC: ADS.1 (VDD), ADS.10 (A3), C1.+, C3.+, DHT.1, F1.2, HT7333.VIN, LVL_SD.J2.3 (HV), PRES1.1, PRES2.1, R1.1, R1.2, R2.1, U$1.5V (VCC), U$1.5V1 (VCC1), U$1.D57 (VCC), U$2.VCC, U$5.VCC, U$6.5V, USB2SERIAL.1
VS: F1.1, SWITCH.1

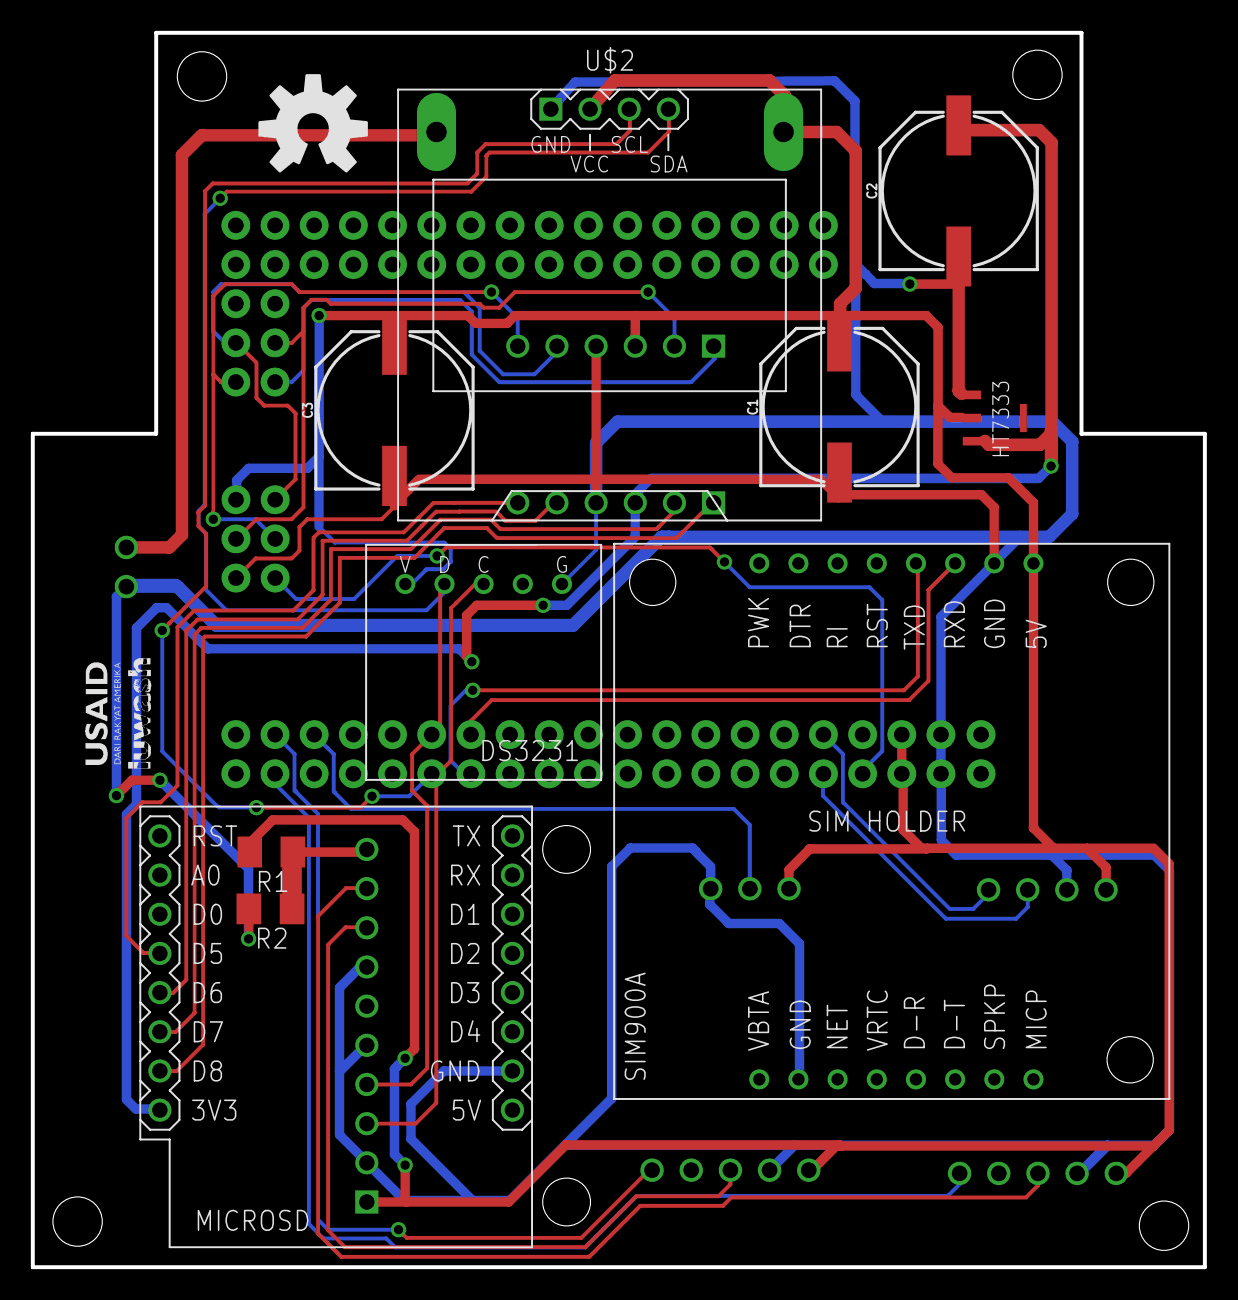
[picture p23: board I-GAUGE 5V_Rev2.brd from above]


Board: 2 copper layers, 76.0 x 80.0 mm, 20 parts (9 on the bottom side), 24 nets.

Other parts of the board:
U$4: OSHW-LOGO-L

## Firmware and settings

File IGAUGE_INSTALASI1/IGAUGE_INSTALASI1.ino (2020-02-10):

/* I-GAUGE V 2019
   BOARD : ARDUINO MEGA 2560


   HISTORY:
   18-2-2019
   FIRST BUILD BY HOLLANDA
   CONFIGURE RTC DS1307  - LIBRARY RTCLIB
   MICRO SD CARD - SDFAT
   ADS1115 - ADS1015
   DISPLAY USING OLED SSD1306 128X64 - ADAFRUIT SSD1306

   24-2-2019
   editing functions
   adding lowpower

   28-2-2019
   GSM connection OK

  problem:
  18-2-2019 cannot be uploaded through icsp - solved
  4-3-2019 oled not displayed the font size properly
*/

//LIBRARY
#include <avr/power.h>
#include <avr/sleep.h>
#include <avr/wdt.h>
#include <SD.h>
#include <Wire.h>
#include "RTClib.h"
#include <Adafruit_Sensor.h>
#include <Adafruit_ADS1015.h>
#include <Adafruit_GFX.h>
#include <Adafruit_SSD1306.h>
#include <TimeLib.h>
#include <TimeAlarms.h>
#include <DHT.h>
#include <LowPower.h>

String ID;
String source = "GSM";
float offset = 0.0;
//server
String url = "";
String server = "";

#define DHTPIN      9
#define DHTTYPE         DHT11
#define oled      0x3c
#define ads_addr    0x48
#define rtc_addr    0x68
#define panjang     128
#define lebar           64
#define pres            0
#define pres1           1
#define tegangan        3
#define connectPres     4
#define connectPres1    6
#define SCKpin          52
#define MISOpin         50
#define MOSIpin         51
#define SSpin           53


// from  http://heliosoph.mit-links.info/arduino-powered-by-capacitor-reducing-consumption/
//defines for DIDR0 setting
#ifndef cbi
#define cbi(sfr, bit) (_SFR_BYTE(sfr) &= ~_BV(bit))
#endif
#ifndef sbi
#define sbi(sfr, bit) (_SFR_BYTE(sfr) |= _BV(bit))
#endif

// create variables to restore the SPI & ADC register values after shutdown
byte keep_ADCSRA;
byte keep_SPCR;

//OLED
#define OLED_RESET 0
Adafruit_SSD1306 display(OLED_RESET);
int16_t posx;
int16_t posy;
uint16_t w, h;

//DHT
DHT dht(DHTPIN, DHTTYPE);

//RTC DS3231
RTC_DS3231 rtc;
DateTime nows;
DateTime sekarang;

//SD CARD
File file;
String filename;

//ADS1115
Adafruit_ADS1115 ads(ads_addr);

//GLOBAL VARIABLE
int i, kode, tahun;
char sdcard[200];
char g;
byte a, b, c, interval, burst;
byte bulan, hari, jam, menit, detik;
char str[13];
unsigned long reads = 0; //pressure
unsigned long waktu, start;
float tekanan, temp, humid, volt;
float longitude = 999.9123;
float latitude = 99.1234;
String y, network, APN, USER, PWD, sms, kuota, noHP, operators, result;

void setup() {
  //initialisation
  Serial.begin(9600);  // Serial USB
  Serial1.begin(9600);  // SIM900A
  pinMode(connectPres, INPUT);
  pinMode(connectPres1, INPUT);
  digitalWrite(connectPres, HIGH);
  digitalWrite(connectPres1, HIGH);

  // disable unused pin function
  ADCSRA = 0; //ADC OFF
  keep_SPCR = SPCR;
  off();

  //WELCOME SCREEN
  s_on();
  Serial.println(F("\r\nWIFI IGAUGE V 2019"));
  Serial.flush();
  s_off();

  i_En(oled);
  display.begin(SSD1306_SWITCHCAPVCC, oled);
  display.clearDisplay();
  display.display();
  delay(10);
  display.setTextSize(1);
  display.setTextColor(WHITE);
  display.setCursor(0, 0);

  display.getTextBounds(F("USAID - PDAM"), 0, 0, &posx, &posy, &w, &h);
  display.setCursor((panjang - w) / 2, 0);
  display.println(F("USAID - PDAM"));
  display.getTextBounds(F("OPEN SOURCE"), 0, 0, &posx, &posy, &w, &h);
  display.setCursor((panjang - w) / 2, 15);
  display.println(F("OPEN SOURCE"));
  display.getTextBounds(F("HARDWARE"), 0, 0, &posx, &posy, &w, &h);
  display.setCursor((panjang - w) / 2, 25);
  display.println(F("HARDWARE"));
  display.getTextBounds(F("WATER PRESSURE"), 0, 0, &posx, &posy, &w, &h);
  display.setCursor((panjang - w) / 2, 35);
  display.println(F("WATER PRESSURE"));
  display.getTextBounds(F("SENSOR DEVICE"), 0, 0, &posx, &posy, &w, &h);
  display.setCursor((panjang - w) / 2, 45);
  display.println(F("SENSOR DEVICE"));
  display.getTextBounds(F("2019"), 0, 0, &posx, &posy, &w, &h);
  display.setCursor((panjang - w) / 2, 55);
  display.println(F("2019"));
  display.display();
  i_Dis();
  LowPower.powerDown(SLEEP_4S, ADC_OFF, BOD_OFF);

  //RTC INIT
  i_En(oled);
  i_En(rtc_addr);
  hapusmenu(15, 64);
  display.getTextBounds(F("INIT CLOCK"), 0, 0, &posx, &posy, &w, &h);
  display.setCursor((128 - w) / 2, 20);
  display.println(F("INIT CLOCK"));
  display.display();
  LowPower.powerDown(SLEEP_2S, ADC_OFF, BOD_OFF);
  s_on();
  if (! rtc.begin()) { // RTC NOT BEGIN
    Serial.println("Couldn't find RTC");
    display.getTextBounds(F("ERROR!! CONTACT CS."), 0, 0, &posx, &posy, &w, &h);
    display.setCursor((128 - w) / 2, 40);
    display.println(F("ERROR!! CONTACT CS."));
    display.display();
    off();
    while (1);
  }

  if (rtc.lostPower()) { // RTC LOST POWER
    Serial.println("RTC LOST POWER!");
    rtc.adjust(DateTime(F(__DATE__), F(__TIME__)));
    display.getTextBounds(F("LOST POWER!"), 0, 0, &posx, &posy, &w, &h);
    display.setCursor((128 - w) / 2, 35);
    display.println(F("LOST POWER!"));
    display.getTextBounds(F("CONTACT CS"), 0, 0, &posx, &posy, &w, &h);
    display.setCursor((128 - w) / 2, 45);
    display.println(F("CONTACT CS"));
    display.display();
    LowPower.powerDown(SLEEP_2S, ADC_OFF, BOD_OFF);
    hapusmenu(35, 64);
    display.getTextBounds(F("SET TIME"), 0, 0, &posx, &posy, &w, &h);
    display.setCursor((128 - w) / 2, 40);
    display.println(F("SET TIME"));
    display.display();
    LowPower.powerDown(SLEEP_2S, ADC_OFF, BOD_OFF);
  }

  nows = rtc.now();
  interval = nows.second();
  while (nows.second() < interval + 3) {
    nows = rtc.now();
    filename = String(nows.month()) + '/' + String(nows.day()) + '/' + String(nows.year()) + ' ' + String(nows.hour()) + ':' + String(nows.minute()) + ':' + String(nows.second());
    Serial.println(filename);
    display.getTextBounds(F("yyyy/mm/dd hh:mm:ss"), 0, 0, &posx, &posy, &w, &h);
    display.setCursor((128 - w) / 2, 40);
    display.print(nows.year());
    display.print("/");
    lcd2digits(nows.month());
    display.print("/");
    lcd2digits(nows.day());
    display.print(" ");
    lcd2digits(nows.hour());
    display.print(":");
    lcd2digits(nows.minute());
    display.print(":");
    lcd2digits(nows.second());
    display.display();
    LowPower.powerDown(SLEEP_120MS, ADC_OFF, BOD_OFF);
  }

  //SD INIT
  LowPower.powerDown(SLEEP_500MS, ADC_OFF, BOD_OFF);
  hapusmenu(17, 64);
  display.getTextBounds(F("init SD Card..."), 0, 0, &posx, &posy, &w, &h);
  display.setCursor((128 - w) / 2, 20);
  display.println(F("INIT SD Card..."));
  display.display();
  pinMode(SSpin, OUTPUT);
  digitalWrite(SSpin, HIGH);
  LowPower.powerDown(SLEEP_2S, ADC_OFF, BOD_OFF);
  spiEn();
  s_on();
  delay(100);
  if (!SD.begin(SSpin)) { //SD ERROR
    Serial.println(F("SD init error!!!"));
    Serial.flush();
    display.getTextBounds(F("SD Card Error!!!"), 0, 0, &posx, &posy, &w, &h);
    display.setCursor((128 - w) / 2, 40);
    display.println(F("SD Card Error!!!"));
    display.display();
    off();
    while (1);
  }

  Serial.println(F("SD CARD INIT OK!"));
  Serial.flush();
  display.getTextBounds(F("SD Card OK!"), 0, 0, &posx, &posy, &w, &h);
  display.setCursor((128 - w) / 2, 40);
  display.println(F("SD Card OK!"));
  display.display();
  off();
  LowPower.powerDown(SLEEP_4S, ADC_OFF, BOD_OFF);

  //GET CONFIG TXT
  hapusmenu(17, 64);
  display.getTextBounds(F("CONFIGURATION FILE"), 0, 0, &posx, &posy, &w, &h);
  display.setCursor((128 - w) / 2, 20);
  display.println(F("CONFIGURATION FILE"));
  display.display();
  LowPower.powerDown(SLEEP_2S, ADC_OFF, BOD_OFF);
  pinMode(SSpin, OUTPUT);
  digitalWrite(SSpin, HIGH);
  spiEn();
  LowPower.powerDown(SLEEP_120MS, ADC_OFF, BOD_OFF);
  configs();
  LowPower.powerDown(SLEEP_2S, ADC_OFF, BOD_OFF);
  off();

  //DISPLAY BURST INTERVAL
  hapusmenu(40, 64);
  display.getTextBounds(F("BURST SAMPLING"), 0, 0, &posx, &posy, &w, &h);
  display.setCursor((128 - w) / 2, 40);
  display.print(F("BURST SAMPLING"));
  display.display();
  LowPower.powerDown(SLEEP_1S, ADC_OFF, BOD_OFF);
  display.getTextBounds(F("10 SECONDS"), 0, 0, &posx, &posy, &w, &h);
  display.setCursor((128 - w) / 2, 52);
  display.print(burst);
  if (burst < 2) {
    display.print(F(" SECOND"));
  }
  else display.print(F(" SECONDS"));
  display.display();
  off();
  LowPower.powerDown(SLEEP_4S, ADC_OFF, BOD_OFF);

  //---------------------------------------------------------------
  //DISPLAY DATA INTERVAL
  hapusmenu(40, 64);
  display.getTextBounds(F("INTERVAL DATA"), 0, 0, &posx, &posy, &w, &h);
  display.setCursor((128 - w) / 2, 40);
  display.print(F("INTERVAL DATA"));
  display.display();
  LowPower.powerDown(SLEEP_1S, ADC_OFF, BOD_OFF);
  display.getTextBounds(F("10 MINUTES"), 0, 0, &posx, &posy, &w, &h);
  display.setCursor((128 - w) / 2, 52);
  display.print(interval);
  if (interval == 1) {
    display.print(F(" MINUTE"));
  }
  if (interval > 1) {
    display.print(F(" MINUTES"));
  }
  display.display();
  off();
  LowPower.powerDown(SLEEP_4S, ADC_OFF, BOD_OFF);

  //check water pressure sensor connected or not
  s_on();
  i_En(ads_addr);
  Serial.println(F("INIT ADS1115"));
  Serial.flush();
  Serial.println(F("CEK PRESSURE SENSOR"));
  Serial.flush();
  ads.begin();
  hapusmenu(17, 64);
  display.getTextBounds(F("CHECK PRESSURE SENSOR"), 0, 0, &posx, &posy, &w, &h);
  display.setCursor((128 - w) / 2, 20);
  display.println(F("CHECK PRESSURE SENSOR"));
  display.display();
  LowPower.powerDown(SLEEP_2S, ADC_OFF, BOD_OFF);
  //cek via ads1115
  reads = digitalRead(connectPres);
  Serial.println(reads);

  if (reads == 1) {
    Serial.println("pressure sensor 1 not connected");
    Serial.flush();
    display.getTextBounds(F("Pressure Sensor"), 0, 0, &posx, &posy, &w, &h);
    display.setCursor((128 - w) / 2, 35);
    display.println(F("Pressure Sensor"));
    display.getTextBounds(F("not connected!!"), 0, 0, &posx, &posy, &w, &h);
    display.setCursor((128 - w) / 2, 50);
    display.println(F("Not Connected!!"));
    display.display();
    off();
    while (1);
  }

  Serial.println("pressure sensor 1 connected");
  display.getTextBounds(F("Pressure sensor"), 0, 0, &posx, &posy, &w, &h);
  display.setCursor((128 - w) / 2, 35);
  display.println(F("Pressure Sensor"));
  display.getTextBounds(F("Connected"), 0, 0, &posx, &posy, &w, &h);
  display.setCursor((128 - w) / 2, 50);
  display.println(F("Connected"));
  display.display();
  off();
  LowPower.powerDown(SLEEP_4S, ADC_OFF, BOD_OFF);


  //DHT INIT
  s_on();
  Serial.println(F("INIT DHT11"));
  Serial.flush();
  hapusmenu(17, 64);
  delay(100);
  dht.begin();
  display.getTextBounds(F("INIT DHT SENSOR"), 0, 0, &posx, &posy, &w, &h);
  display.setCursor((128 - w) / 2, 20);
  display.println(F("INIT DHT SENSOR"));
  display.display();
  LowPower.powerDown(SLEEP_2S, ADC_OFF, BOD_OFF);
  display.getTextBounds(F("DHT READY!!"), 0, 0, &posx, &posy, &w, &h);
  display.setCursor((128 - w) / 2, 40);
  display.println(F("DHT READY!!"));
  display.display();
  off();
  LowPower.powerDown(SLEEP_4S, ADC_OFF, BOD_OFF);


  //INIT SIM900A & SEND SMS
  i_En(oled);
  s_on();
  Serial.println(F("INITIALIZATION SIM900A..."));
  Serial.flush();
  s_off();
  hapusmenu(17, 64);
  display.getTextBounds(F("INIT GSM MODULE"), 0, 0, &posx, &posy, &w, &h);
  display.setCursor((128 - w) / 2, 20);
  display.println(F("INIT GSM MODULE"));
  display.display();
  LowPower.powerDown(SLEEP_2S, ADC_OFF, BOD_OFF);
  sim();

  i_En(oled);
  display.getTextBounds(F("Finish!!!"), 0, 0, &posx, &posy, &w, &h);
  display.setCursor((128 - w) / 2, 50);
  display.print(F("Finish!!!"));
  display.display();
  off();
  LowPower.powerDown(SLEEP_4S, ADC_OFF, BOD_OFF);

  display.clearDisplay();
  displaydate();
  nows = rtc.now();
  setTime(nows.hour(), nows.minute(), nows.second(), nows.month(), nows.day(), nows.year());
  Alarm.timerRepeat(60 * interval, ambil);

  //display menu parameter
  hapusmenu(17, 64);
  display.setCursor(0, 17);  display.print(F("Pres"));
  display.setCursor(0, 30);  display.print(F("Temp"));
  display.setCursor(0, 40);  display.print(F("Humid"));
  display.setCursor(0, 50);  display.print(F("Volt"));

  display.setCursor(32, 17);  display.print(F("="));
  display.setCursor(32, 30);  display.print(F("="));
  display.setCursor(32, 40);  display.print(F("="));
  display.setCursor(32, 50);  display.print(F("="));

  display.setCursor(73, 17);  display.print(F("bar"));
  display.setCursor(73, 25);  display.print("o");
  display.setCursor(78, 30);  display.print("C");
  display.setCursor(75, 40);  display.print(F("RH"));
  display.setCursor(75, 50);  display.print(F("V"));

  //display.setCursor(100,52);  display.print(F("ERR"));
  display.display();
  off();
  ambil();
}

void loop() {
  Alarm.delay(0)  ;
}

void bersihdata() {
  Alarm.delay(0);
  reads = '0'; tekanan = '0'; temp = '0'; humid = '0'; volt = '0';
  filename = ""; y = "";
}

void ambil() {
  on();
  Alarm.delay(0);
  displaydate();
  hapusmenu(100, 52);
  //WAKE UP GSM
  Serial.println(F(" "));
  Serial.println(F("AT+CSCLK=0"));
  Serial1.println(F("AT+CSCLK=0"));
  Serial1.flush();
  delay(200);
  Serial1.println(F("AT+CSCLK=0"));
  Serial1.flush();
  bacaserial(200);

  sekarang = rtc.now();
  tahun = sekarang.year();
  bulan = sekarang.month();
  hari = sekarang.day();
  jam = sekarang.hour();
  menit = sekarang.minute();
  detik = sekarang.second();
  waktu = sekarang.unixtime();
  bersihdata();

  // burst sampling
  for (i = 0; i < burst; i++) {
    displaydate();
    reads += ads.readADC_SingleEnded(0); //pressure
    LowPower.powerDown(SLEEP_1S, ADC_OFF, BOD_OFF);
  }

  //KONVERSI
  volt = ((float)reads / (float)burst) * 0.1875 / 1000.0000; // nilai voltase dari nilai DN
  tekanan = (300.00 * volt - 150.00) * 0.01 + float(offset);
  reads = ads.readADC_SingleEnded(tegangan);
  volt = (float)reads * 0.1875 / 1000.0000 * 3.0000 / 2.00000; // nilai voltase dari nilai DN
  humid = dht.readHumidity();      //humid
  temp = dht.readTemperature();    //temperature
  if (isnan(humid)) {
    humid = -99.9;
  }
  if (isnan(temp)) {
    temp = -99.9;
  }

  //display data
  displaydate();
  display.fillRect(40, 17, 32, 64, BLACK); //clear display
  display.fillRect(100, 52, 32, 64, BLACK); //clear display
  display.display();
  display.setCursor(40, 17);  display.print(tekanan, 1);
  display.setCursor(40, 30);  display.print(temp, 1);
  display.setCursor(40, 40);  display.print(humid, 1);
  display.setCursor(40, 50);  display.print(volt, 1);
  display.display();

  //debug serial
  displaydate();
  Serial.print(F("PRESSURE = "));
  Serial.println(tekanan, 1);
  Serial.print(F("TEMPERATURE = "));
  Serial.println(temp, 1);
  Serial.print(F("HUMIDITY = "));
  Serial.println(humid, 1);
  Serial.print(F("VOLTAGE = "));
  Serial.println(volt, 1);
  Serial.flush();

  //SIMPAN DATA
  ID = "0001";
  displaydate();
  Serial.println(F("Simpan data"));
  Serial.flush();
  simpandata();

  //KIRIM data
  displaydate();
  s_on();
  Serial.println(F("SEND DATA TO SERVER"));
  Serial.flush();
  s_off();
  sendServer();

  //kode network
  displaydate();
  spiEn();
  s_on();
  Serial.println(F("simpan kode network"));
  Serial.flush();
  s_off();
  file = SD.open(filename, FILE_WRITE);
  file.print(kode);
  file.print(",");
  file.println(network);
  delay(100);
  file.close();

  //display kode network
  displaydate();
  i_En(oled);
  display.setCursor(100, 52);  display.print(kode);
  display.display();
  s_on();
  s1_on();
  Serial.println(F("AT+CSCLK=2"));
  Serial1.println(F("AT+CSCLK=2"));
  Serial.flush();
  Serial1.flush();
  off();

  while (1) {
    displaydate();
    setTime(nows.hour(), nows.minute(), nows.second(), nows.month(), nows.day(), nows.year());
    int start = nows.unixtime() - waktu;
    s_on();
    Serial.println(start);
    Serial.flush();
    s_off();
    off();
    if (start < ((interval * 60) - 15)) {
      LowPower.powerDown(SLEEP_8S, ADC_OFF, BOD_OFF);
      LowPower.powerDown(SLEEP_2S, ADC_OFF, BOD_OFF);

    }
    if (start < ((interval * 60) - 5)) {
      LowPower.powerDown(SLEEP_2S, ADC_OFF, BOD_OFF);
    }
    else {
      break;
    }
  }
  i_En(rtc_addr);
  displaydate();
  setTime(nows.hour(), nows.minute(), nows.second(), nows.month(), nows.day(), nows.year());
  s_on();
  Serial.println("ready to get data");
  Serial.flush();
  s_off();
}

void simpandata() {
  Alarm.delay(0);
  spiEn();
  SdFile::dateTimeCallback(dateTime);
  filename = "";
  filename = String(tahun);
  if (bulan < 10) {
    filename += "0" + String(bulan);
  }
  if (bulan >= 10) {
    filename += String(bulan);
  }
  if (hari < 10) {
    filename += "0" + String(hari);
  }
  if (hari >= 10) {
    filename += String(hari);
  }
  filename += ".txt";

  Serial.println(filename);
  Serial.flush();

  displaydate();
  file = SD.open(filename, FILE_READ);
  a = file.available();
  file.close();

  // set date time callback function
  SdFile::dateTimeCallback(dateTime);
  file = SD.open(filename, FILE_WRITE);
  if (a == 0) {
    Serial.println(filename);
    file.print(F("Date (YYYY-MM-DD HH:MM:SS),"));
    file.print(F(" ID, Pressure (BAR), Temperature (°C), Humidity (RH), "));
    file.println(F("Voltage (V), Burst interval (SECOND), Data Interval (MINUTE), Network Code, Response")); //
  }

  y = "";
  y = String(tahun) + '/';
  if (bulan < 10) {
    y += "0" + String(bulan);
  }
  if (bulan >= 10) {
    y += String(bulan);
  }
  y += "/";
  if (hari < 10) {
    y += "0" + String(hari);
  }
  if (hari >= 10) {
    y += String(hari);
  }
  y += " ";
  if (jam < 10) {
    y += "0" + String(jam);
  }
  if (jam >= 10) {
    y += String(jam);
  }
  y += ":";
  if (menit < 10) {
    y += "0" + String(menit);
  }
  if (menit >= 10) {
    y += String(menit);
  }
  y += ":";
  if (detik < 10) {
    y += "0" + String(detik);
  }
  if (detik >= 10) {
    y += String(detik);
  }
  y += ", " + String(ID) + ", " + String(tekanan, 2) + ", " + String(temp, 2);
  y += ", " +  String(humid, 2) + ", " + String(volt, 2) + ", " + String(burst) + ", " + String(interval) + ", " ;

  Serial.println(y);
  file.print(y);
  delay(100);
  file.close();
  displaydate();
}

void configs() {
  i = 0;
  file = SD.open(F("config.txt"));
  if (file) {
    while (file.available()) {
      sdcard[i++] = file.read();
    }
  }
  else  { //error reading
    s_on();
    Serial.println(F("ERROR READING!!!"));
    display.getTextBounds(F("ERROR READING!!!"), 0, 0, &posx, &posy, &w, &h);
    display.setCursor((128 - w) / 2, 40);
    display.println(F("ERROR READING!!!"));
    display.display();
    off();
    while (1);
  }
  file.close();

  filename = String(sdcard);
  for ( a = 0; a < sizeof(sdcard); a++) { //clear variable
    sdcard[a] = (char)0;
  }

  s_on();
  Serial.println(filename);
  Serial.flush();
  display.getTextBounds(F("SUCCESS!!!"), 0, 0, &posx, &posy, &w, &h);
  display.setCursor((128 - w) / 2, 40);
  display.println(F("SUCCESS!!!"));
  display.display();
  Serial.println(F("GET CONFIG SUCCESS!!!"));
  Serial.flush();
  b = 0;

  //ID
  a = filename.indexOf("=", b + 1);
  b = filename.indexOf("\r", a + 1);
  ID = filename.substring(a + 2, b);

  //interval data
  a = filename.indexOf("=", b + 1);
  b = filename.indexOf("\r", a + 1);
  interval = filename.substring(a + 1, b).toInt();

  //burst interval
  a = filename.indexOf("=", b + 1);
  b = filename.indexOf("\r", a + 1);
  burst = filename.substring(a + 1, b).toInt();

  //no HP
  a = filename.indexOf("=", b + 1);
  b = filename.indexOf("\r", a + 1);
  noHP = filename.substring(a + 2, b);

  //LATITUDE
  a = filename.indexOf("=", b + 1);
  b = filename.indexOf("\r", a + 1);
  y = filename.substring(a + 2, b);
  latitude = y.toFloat();

  //LONGITUDE
  a = filename.indexOf("=", b + 1);
  b = filename.indexOf("\r", a + 1);
  y = filename.substring(a + 2, b);
  longitude = y.toFloat();

  filename = '0';

  Serial.print(F("Station Name = "));
  Serial.println(ID);
  Serial.print(F("Interval data = "));
  Serial.print(interval);
  if (interval < 2)
    Serial.println(F(" minute"));
  else Serial.println(F(" minutes"));
  Serial.print(F("Burst Interval = "));
  Serial.print(burst);
  if (interval < 2)
    Serial.println(F(" second"));
  else Serial.println(F(" seconds"));
  Serial.print(F("NO HP = "));
  Serial.println(noHP);
  Serial.print(F("Latitude = "));
  Serial.println(latitude);
  Serial.print(F("Longitude = "));
  Serial.println(longitude);

  Serial.flush();
}

void hapusmenu(byte h, byte h1) {
  i_En(oled);
  display.fillRect(0, h, 128, h1, BLACK); //clear display
  display.display();
  display.setTextColor(WHITE, BLACK);
}

void lcd2digits(int number) {
  if (number >= 0 && number < 10) {
    display.write('0');
  }
  display.print(number);
}

void displaydate() {
  i_En(rtc_addr);
  i_En(oled);
  nows = rtc.now();
  display.getTextBounds(F("yyyy/mm/dd hh:mm "), 0, 0, &posx, &posy, &w, &h);
  //display.fillRect(0, 2, 128, h, BLACK); //clear display
  display.setTextColor(WHITE, BLACK);
  display.setCursor((128 - w), 0);
  display.print(nows.year()); display.print("/");
  lcd2digits(nows.month()); display.print("/");
  lcd2digits(nows.day()); display.print(" ");
  lcd2digits(nows.hour()); display.print(":");
  lcd2digits(nows.minute());
  display.display();
}

void dateTime(uint16_t* date, uint16_t* time) {
  nows = rtc.now();
  // return date using FAT_DATE macro to format fields
  *date = FAT_DATE(nows.year(), nows.month(), nows.day());

  // return time using FAT_TIME macro to format fields
  *time = FAT_TIME(nows.hour(), nows.minute(), nows.second());
}
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

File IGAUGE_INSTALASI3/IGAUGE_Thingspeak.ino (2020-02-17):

// IOT PRESSURE DATA LOGGER
// SENDING TO THINGSPEAK
// BOARD : ARDUINO PRO MINI
// DEVELOPED BY : MANTIS ID
// REVISED : 2020-2-16

#include <SoftwareSerial.h>

// nilai burst
const byte burst = 5;
const byte interval =1;

//KONFIGURASI IP. Pilih salah satu
String IP = "Telkomsel";
const char USER[] = "";
const char PWD[] = "";

//api key
String SECRET_WRITE_APIKEY = "SB97TGUB7QFMNJN9";  // replace XYZ with your channel write API Key

//pin sensor tekanan
#define pressurePin A1  // Put the data cable to pin A1

//KONFIGURASI SOFTWARE SERIAL
SoftwareSerial SIM7000(6, 7); // RX, TX 6,7

//KONFIGURASI PIN
#define powerSensor 4 // pin untuk menyalakan sensor
#define key 5         // pin power key
#define ledOK 2       // pin LED untuk tanda OK - 2
#define ledERROR 3    // pin LED untuk tanda ERROR - 3

String kalimat;
unsigned long mulai;
float tekanan;
char json[80];

void setup() {
  Serial.begin(9600);
  Serial.println(F("WATER PRESSURE SENSOR PDAM THINGSPEAK 2020"));
  delay(1000);
  Serial.println(F("- INISIALISASI SERIAL GSM "));
  SIM7000.begin(9600);
  delay(1000);

  Serial.println(F("< ATUR LED OK DAN LED ERROR >"));
  pinMode(ledOK, OUTPUT);
  pinMode(ledERROR, OUTPUT);
  pinMode(powerSensor, OUTPUT);
  pinMode(key, OUTPUT);
  delay(1000);

  Serial.println(F("< NYALAKAN LED >"));
  digitalWrite(ledOK, HIGH);
  delay(1000);
  digitalWrite(ledERROR, HIGH);
  delay(1000);
  digitalWrite(ledOK, 0);
  digitalWrite(ledERROR, 0);
  delay(1000);

  Serial.println(F("Tunggu Modul GSM Aktif - 20 detik"));
  delay(1000);
  for (byte i = 1; i <= 20; i++) {
    Serial.print(i);
    Serial.println(F(" detik"));
    digitalWrite(ledOK, 1);
    delay(700);
    digitalWrite(ledOK, 0);
    delay(300);
  }

  //INIT GSM
  Serial.println(F("\r\n- INIT GSM -"));
  initGSM();
  delay(1000);

}

void loop() {
  unsigned long Start=millis();
  Serial.println(F("\r\n- PENGAMBILAN DATA -"));
  Serial.println(F("\r\n< AMBIL DATA SENSOR >"));
  digitalWrite(powerSensor, 1);
  sensor();
  digitalWrite(powerSensor, 0);

  //cek data tekanan di serial monitor
  Serial.print(F("Tekanan="));
  Serial.print(tekanan);
  Serial.println(F(" bar\n"));

  Serial.println(F("\r\n<- KIRIM DATA KE THINGSPEAK ->"));
  gprsComm();
  sendServer();  //kirim data

  sisamemori();

  unsigned long Stop=millis();
  unsigned long sisa=interval * 60UL * 1000UL - (Stop - Start);
  Serial.println(sisa);
  unsigned long bagi=0;
  while(bagi<sisa){
    bagi=millis()-Stop;
    Serial.println(bagi);
    digitalWrite(ledOK,0);
    delay(700);
    digitalWrite(ledOK,1);
    delay(300);
  }

  sisamemori();
  digitalWrite(ledOK,0);
}

// ROUTINE FOR GSM
void initGSM() {
  // AT
  Serial.println(F("\r\n- CEK AT -"));
  at();

  // Check pin and functionality
  Serial.println(F("\r\n- CPIN & CFUN -"));
  gsmCheckFunc();
  delay(1000);

  // DEFINE PDP CONTEXT
  Serial.println(F("\r\n- ATUR PDP -"));
  gsmPDP();
  delay(1000);

  // REGISTRASI KARTU KE NETWORK PROVIDER
  Serial.println(F("\r\n- REGISTRASI KE NETWORK -"));
  gsmRegister();
  delay(1000);

  // CEK OPERATOR
  Serial.println(F("\r\n- CEK OPERATOR -"));
  gsmOperator();
  delay(1000);

  // CEK KEKUATAN SINYAL
  Serial.println(F("\r\n- CEK KEKUATAN SINYAL -"));
  gsmSignal();
  delay(1000);
}

char cekSerial(unsigned int times) {
  boolean indeks = 0;
  char karakter;
  unsigned long mulai = millis();
  while (millis() - mulai < times) {
    while (SIM7000.available() > 0) {
      karakter = SIM7000.read();
      Serial.write(karakter);
      if (karakter == 'O' || karakter == 'E') {
        indeks = 1;
        break;
      }
    }
    if (indeks == 1) break;
  }
  
  mulai = millis();
  while (millis() - mulai < 100) {
    while (SIM7000.available() > 0) {
      Serial.write(SIM7000.read());
    }
  }

  Serial.write(13);
  Serial.write(10);

  return karakter;
}

String bacaserial(unsigned int wait) {
  String kalimat = "";
  unsigned long mulai = millis();
  while ((mulai + wait) > millis()) {
    while (SIM7000.available() > 0) {
      char karakter = SIM7000.read();
      Serial.write(karakter);
      kalimat += karakter;
    }
  }
  SIM7000.flush();
  return kalimat;
}

void at() {
  for (byte i = 0; i < 6; i++) {
    SIM7000.println(F("AT"));
    char output = cekSerial(200);
    if (i == 5 && output != 'O') {
      Serial.println(F("GSM MODULE ERROR"));
      Serial.println(F("CONTACT CS!!!"));
      while (1);
    }
    if(output=='O') break;
    delay(1000);
  }
}

// Pengecekan kesiapan kartu dari pin dan functionality
void gsmCheckFunc() {
  SIM7000.println(F("AT+CPIN?;+CFUN=1"));
  cekSerial(200);
}

//set PDP context
void gsmPDP() {
  String output;
  output = "AT+CGDCONT=1,\"IP\",\"";
  output.concat(String(IP));
  output.concat("\"");
  SIM7000.println(output);
  cekSerial(500);
  output = "AT+CGDCONT=13,\"IP\",\"";
  output.concat(String(IP));
  output.concat("\"");
  SIM7000.println(output);
  cekSerial(500);
}

void gsmOperator() {
  byte i = 0;
  byte indeks = 255;
  while (indeks == 255) {
    String output = "";
    SIM7000.println(F("AT+COPS?"));
    output = bacaserial(200);
    indeks = output.indexOf("\"", 0);
    Serial.println(indeks);
    delay(2000);
    if (indeks == 255) {
      i++;
      if (i == 20) {
        Serial.println(F("OPERATOR PROVIDER TIDAK DITEMUKAN"));
        initGSM();
      }
    }
  }
}

void gsmRegister() {
  SIM7000.println(F("AT+CREG=1"));
  cekSerial(200);
}

void gsmSignal() {
  SIM7000.println(F("AT+CSQ"));
  cekSerial(200);
}

void sensor() {
  unsigned long nilai = 0;
  float pressVolt = 0;
  tekanan = 0.00;

  for (byte indeks = 0; indeks < burst; indeks++) {
    int pressADC = analogRead(pressurePin);
    nilai += pressADC;
  }

  pressVolt = (float (nilai / burst) / 1024.00 * 5.00);
  tekanan = (3.00 * pressVolt - 1.5);// - offset; // satuan bar
  if(tekanan <0) tekanan =0.00;
}

boolean gprsComm() {
  Serial.println(F("\r\n- TUTUP DULU GPRS -"));
  gprsShut();
  gsmShut();
  delay(200);

  // SET SINGLE IP CONNECTION
  Serial.println(F("\r\n- ATUR CIPMUX MENJADI SINGLE IP CONNECTION -"));
  gprsMux();
  delay(200);

  // DEFINE PDP CONTEXT
  Serial.println(F("\r\n- ATUR PDP -"));
  gsmPDP();

//  // ACTIVATE PDP CONTEXT
//  Serial.println(F("\r\n- AKTIVASI PDP -"));
//  while (PDPactivate() != 'O');

  //Attach from GPRS Service
  Serial.println(F("\r\n- AKTIFKAN GPRS SERVICE -"));
  gprsAttach();
  delay(200);

  //mulai task and set APN, user name, password
  Serial.println(F("\r\n- SET TCP IP APN -"));
  gprsCSTT();

  //Bring Up Wireless Connection with GPRS
  //  konek = gprsWirelessConnect();
  Serial.println(F("\r\n- CONNECTING TCP IP -"));
  if (gprsWirelessConnect() == 0) return 0;
  Serial.println(F("- CONNECTED -"));

  //Get Local IP Address
  Serial.println(F("\r\n- LOCAL IP ADDRESS  -"));
  gprsIP();

  return 1;
}

void gprsAttach() {
  // ATTACH gprs SERVICE
  SIM7000.println(F("AT+CGATT=1"));
  cekSerial(200);
}
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

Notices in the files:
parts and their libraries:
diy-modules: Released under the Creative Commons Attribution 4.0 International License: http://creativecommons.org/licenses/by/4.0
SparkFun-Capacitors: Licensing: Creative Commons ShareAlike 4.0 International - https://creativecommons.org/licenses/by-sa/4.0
